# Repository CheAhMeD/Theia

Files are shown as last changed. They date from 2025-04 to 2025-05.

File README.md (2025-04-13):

# Theia Thermal Imaging Camera

<br>


Theia is an open source thermal camera designed around the ESP32-S3 and Lepton 3.5. <br>
It is started as a way to explore the Lepton 3.5 sensor and its abilities and turned to be a full (yet simple) thermal camera.

## Theia Camera
Theia is a well featured, open source camera with a local touchscreen display, local storage and a USB interface. <br>
It is composed of a custom PCB and a custom 3D enclosure (with optional stand).

<br>
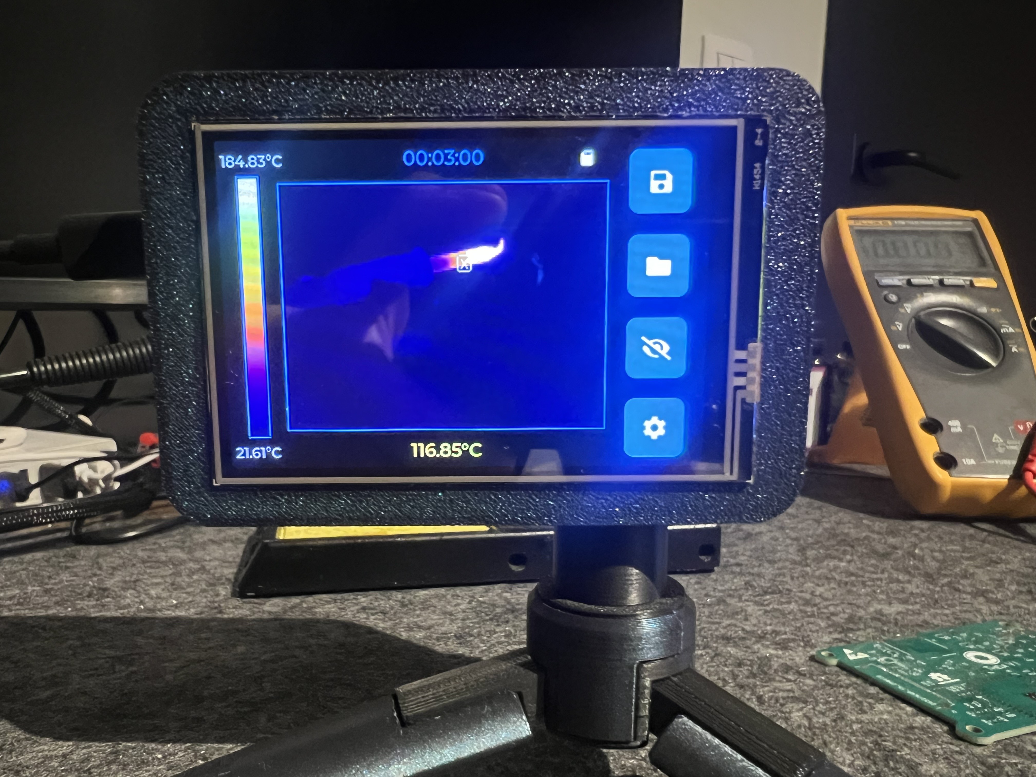
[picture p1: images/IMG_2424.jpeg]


## PCB
The PCB has been created with KiCAD software. <br>
Theia V1 Schematics are available in PCB Folder.<br>
The project is open source (If you need the KiCad project files drop a message). <br>
Please use the gerber files provided [here](/PCB/production.zip) if you want to order a PCB (The impedance control is important for the USB part to work). 

<br>
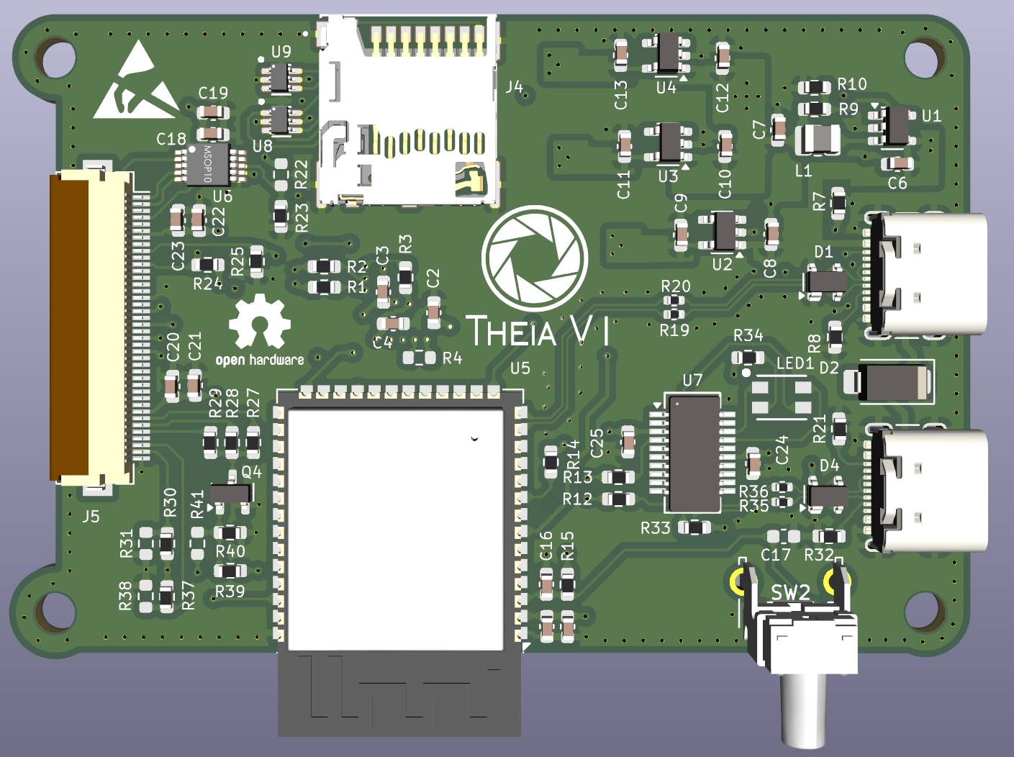
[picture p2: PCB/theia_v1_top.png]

<br>
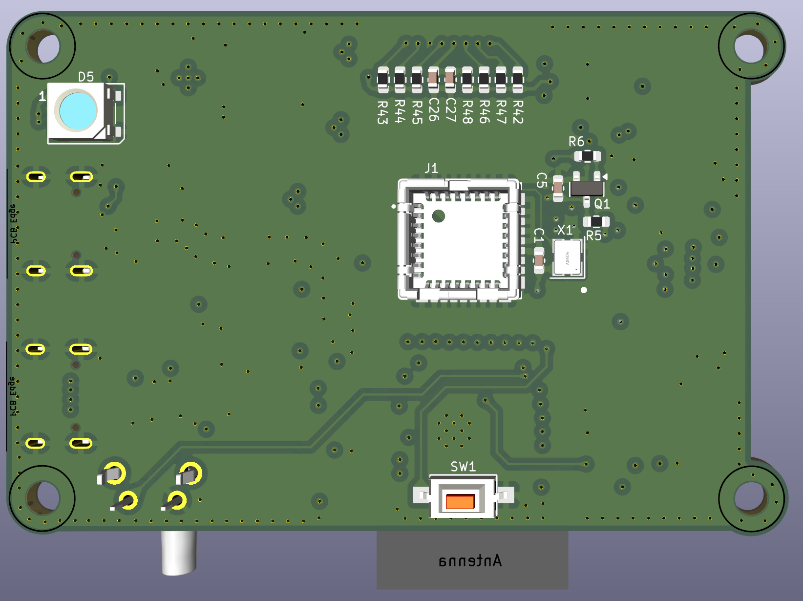
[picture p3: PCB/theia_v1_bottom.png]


## Firmware
The "Firmware" directory contains an Arduino IDE project for Theia (version 1). You should be able to build and load it into a camera using the normal process.

### Note:
Due to the custom pcb (no board package provided), to be able to upload the compiled firmware you need to set the Arduino Environment as follow:
<br>
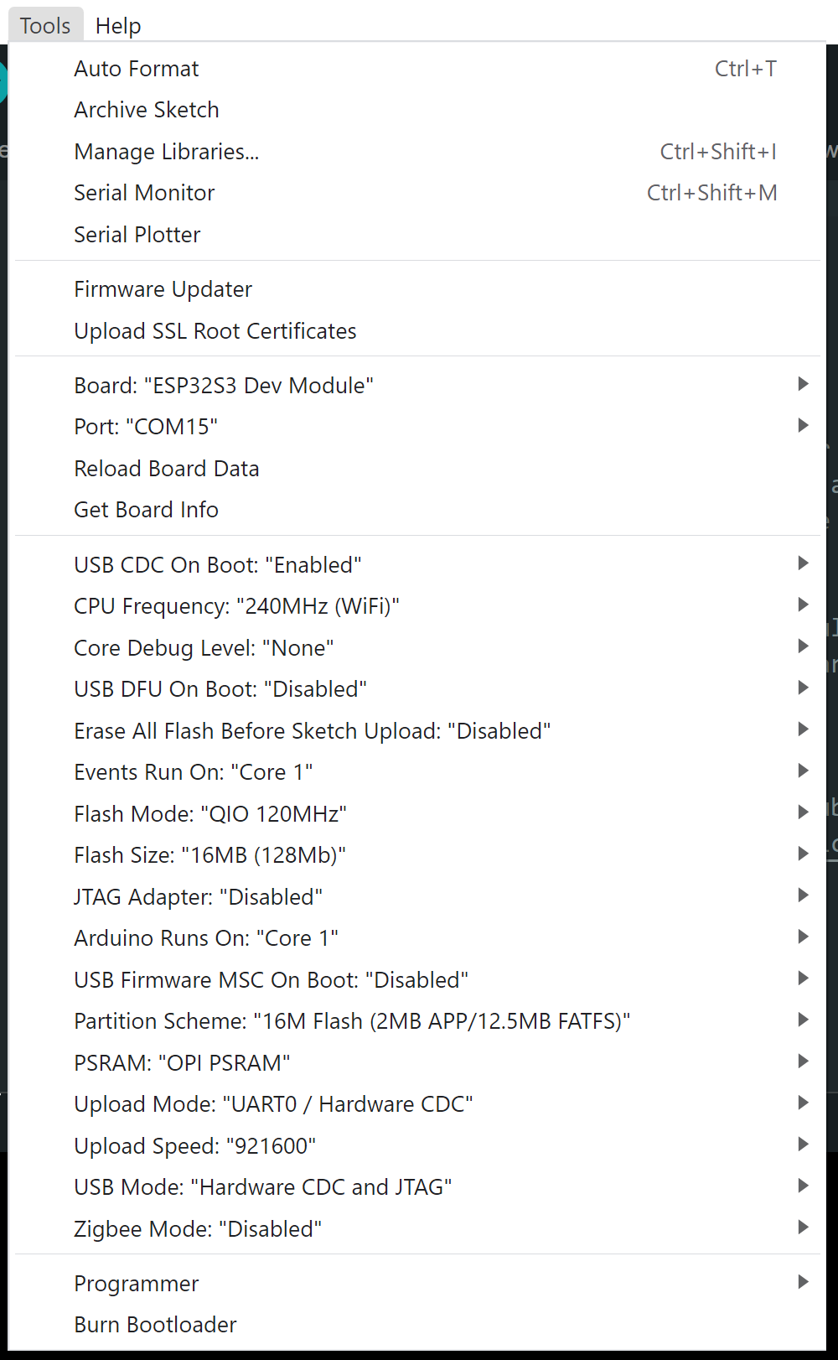
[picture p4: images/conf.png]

<br>
<br>
More details on the Firmware are available in /Firmware/README.md

## Enclosure
A simple 2 piece enclosure designed to be 3D printed. Design was done with the online editor "onshape". <br>
The OnShape project folder can be accessed [here](https://cad.onshape.com/documents/da13b0f788f852a632ae2d5d/w/38727c48ed0b2ebb656da7c0/e/01333a5db09d1259df274e6b) and the generated STL files are included in the Enclosure directory.

<br>
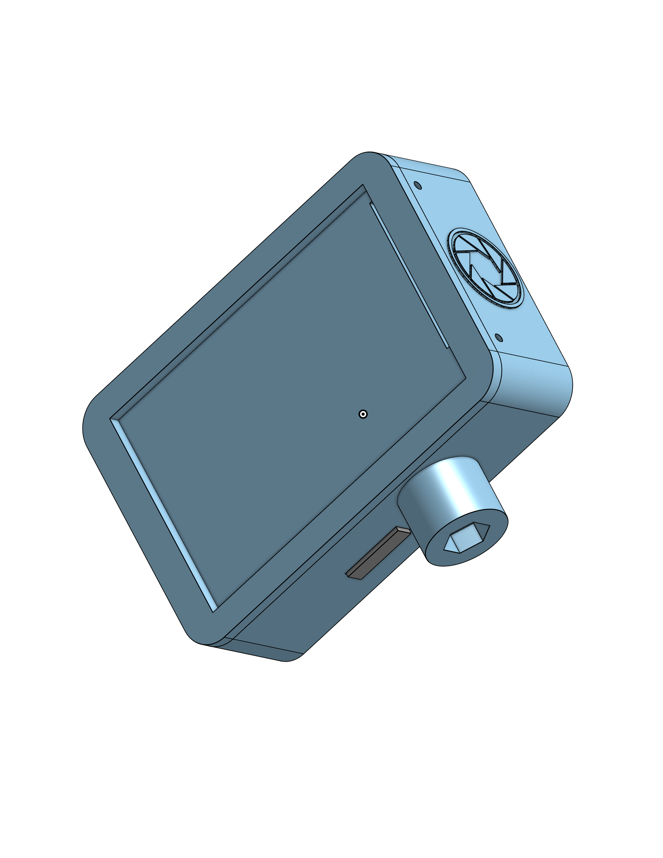
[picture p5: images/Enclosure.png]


## Desktop App
This DesktopApp folder contains the companion desktop application for Theia. It communicates with the cameras via a USB (Serial) connection using a predefined set of commands. 
It provides very basic functionalities to control the cameras, download and display images from them and analyze the radiometric data.

More details on the DesktopApp are available in /DesktopApp/README.md

## Python Examples
Simple Examples using a python script to perform basic operations on the camera.

## Acknowledgements
A lot of useful information were collected thanks to the brilliant work done in tCam (By [Dan Julio](https://github.com/danjulio)) and diy-thermocam (By [Max Ritter](https://github.com/maxritter))

 - [tCam](https://github.com/danjulio/tCam)
 - [DIY-Thermocam](https://github.com/maxritter/diy-thermocam)

## Authors

- [Che Ahmed](https://github.com/CheAhMeD)

## Badges



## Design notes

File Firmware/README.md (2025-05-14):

# Theia Thermal Camera - Firmware

Theia firmware V1 is an Arduino IDE project. You need to have the Arduino core for the ESP32 installed to build the firmware. <br>

## Dependencies 

[Display Driver] LovyanGFX 1.2.0 (a small modification needed for IPS Displays) <br>
[GUI] LVGL 8.3.0 <br> 
[Timer] ESP32Time 2.0.6 <br>
[Status Led] FastLED 3.9.13 <br>
[CRC] CRC 1.0.3 (Rob Tillaart)

## Operating

Theia can be controlled locally using the graphics user interface (Theia GUI) or remotely using a command-based interface (Theia Serial) available via USB. Both interfaces are detailed below.

### Theia USB Connector 1
The first USB Connector is used mainly for debug purposes (baud 115200) but it can be used to provide power to the camera. (By default the debug interface is disabled).

### Theia USB Connector 2
The USB connector is used to provide power to the camera and as a programming/control interface for Theia. This port is used by Theia Tool v1.0.0b to access the camera.

### Theia SD Card
Image files (RAW or BMP) are stored in the attached SD card. If none is attached the firmware will detect the absence of the SD Card and the user won't be able to save any images nor browse the content of the card. <br> Files are saved under RAW or BMP format (.timg or .bmp) after being scaled to 320x240.

#### Note:
**The SD Card must be formatted in FAT32.**
**Theia Hardware doesn't provide a Card Detect signal, the firmware uses a dumb routines that checks if a certain file (.theia) exists on the SD Card to determine that the SD Card is attached. The file ".theia" is created at boot if it doesnt exist.**

## Theia GUI

<br>
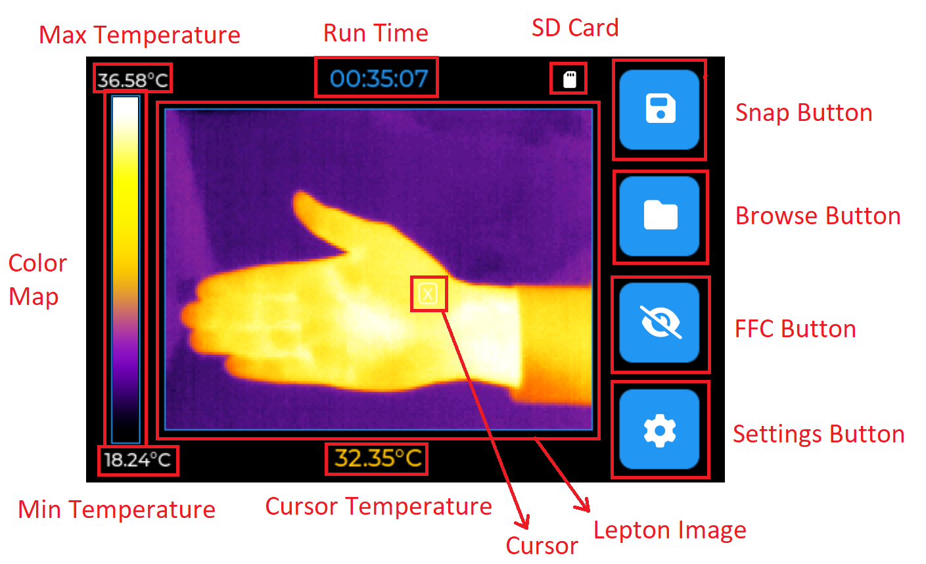
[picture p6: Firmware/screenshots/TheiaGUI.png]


### Boot Screen

A timed out screen that displays the logo and a boot log message.

<br>
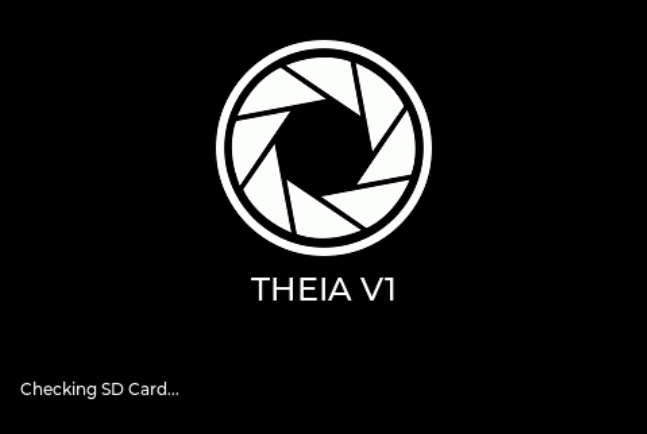
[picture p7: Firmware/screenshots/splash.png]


### Main Screen 

Camera main screen that contain the lepton stream and some controls.

<br>
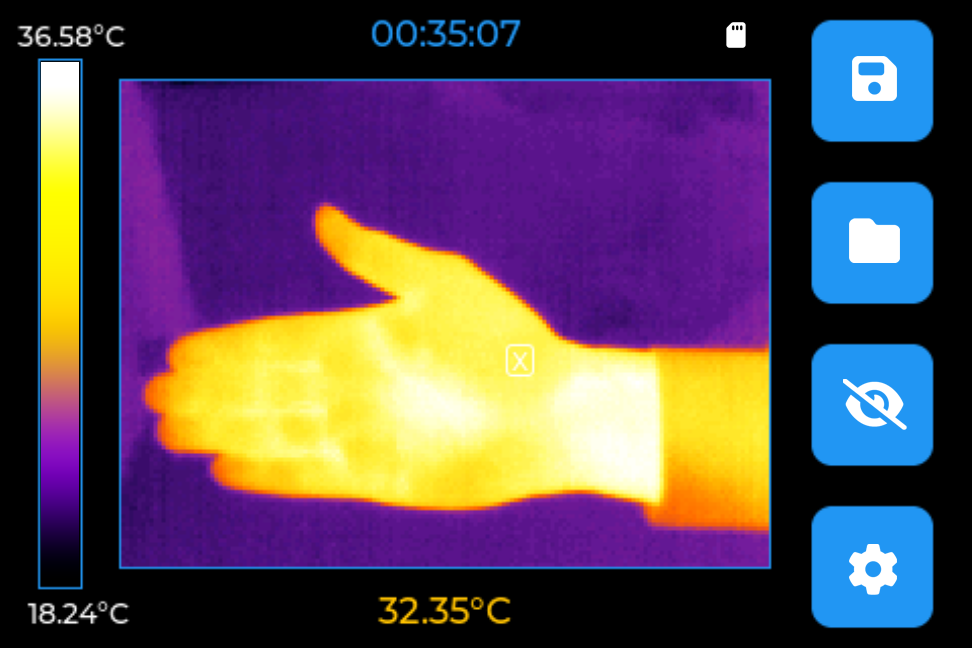
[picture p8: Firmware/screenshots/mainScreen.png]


#### Controls

| **Control** | **Function** |
|---|---|
| Snap Button  | Takes a snap and saves a BMP/TIMG image in the SD card under "Lepton" directory (a status message box will appear once pressed). |
| Browse Button  | Opens the browse screen. |
| FFC Button | Performs a manual FFC. |
| Settings Button | Opens the settings screen.  |
|  Cursor | Pressing on the lepton image updates the cursor position and the cursor temperature. |

### Browse Screen

SD card browse screen. A very simple gui to browse and display the content of "Lepton" directory. <br>
It shows the file name, file number and total files in the directory.

<br>
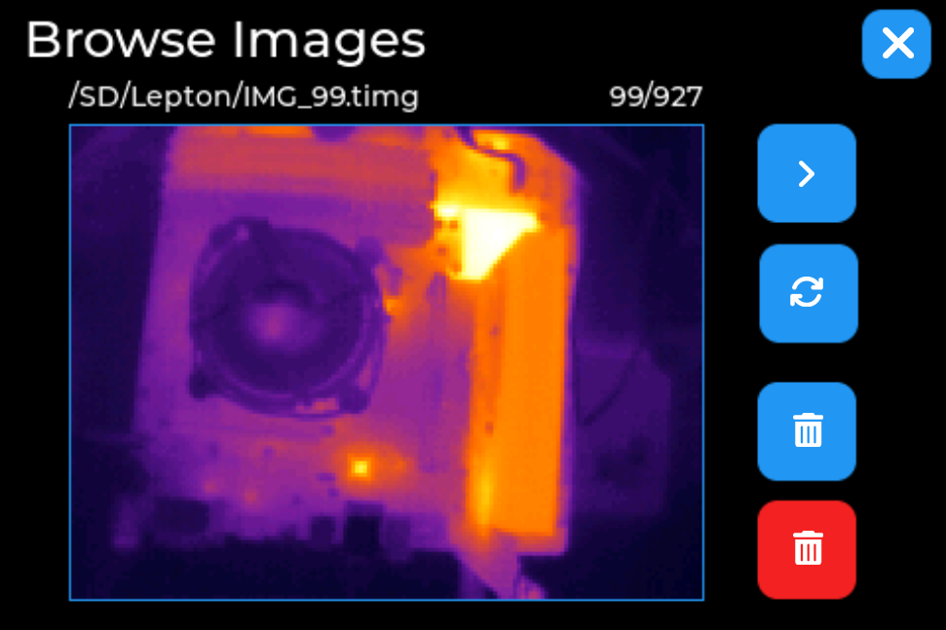
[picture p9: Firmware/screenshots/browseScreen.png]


#### Controls

| **Button** | **Function** |
|---|---|
| Close Button  | Returns to the main screen. |
| Next Button  | Displays the next image file. |
| Rewind Button | Goes back to the first file in the directory. |
| Detete Button | (In blue) Deletes the current displayed image (a confirmation message box will appear once pressed).  |
|  Delete All Button | (In red) Deletes all the files in Lepton Directory (a confirmation message box will appear once pressed).  |

### Settings Screen

Camera settings screen. It offers some controls over the behaviour of the camera as well as some controls over the lepton sensor.

<br>
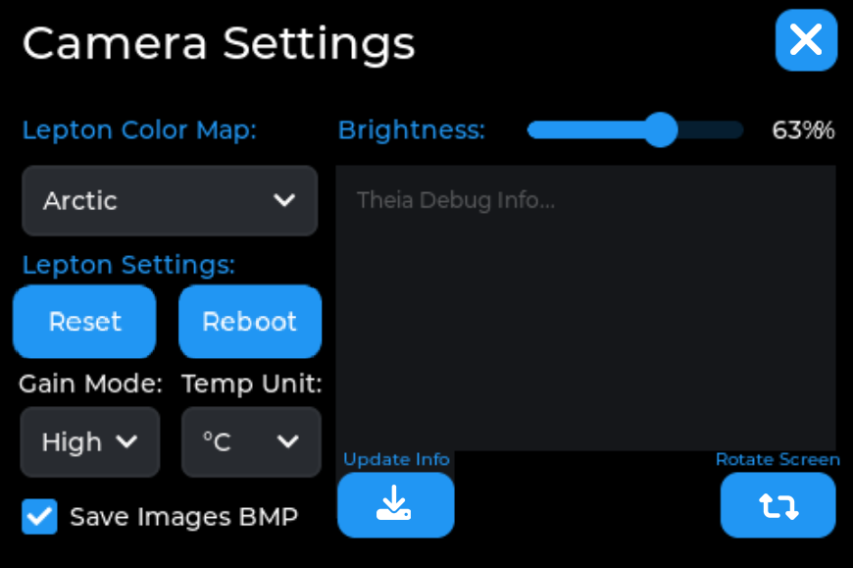
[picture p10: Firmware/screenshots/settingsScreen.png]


#### Controls

| **Control** | **Function** |
|---|---|
| Close Button  | Returns to the main screen. |
| Lepton Color Map | Updates the color map of the lepton image from the available 12 palettes. |
| Reset Button | Resets the lepton sensor (a status message box will appear once pressed).  |
| Reboot Button | Reboots the lepton sensor (a status message box will appear once pressed). |
| Gain Mode | Updates the lepton gain mode (High / Low / Auto). |
| Temp Unit | Updates the temperature unit (°C / °F / K). |
| Save Image BMP | Switches between .bmp / .timg formats for the saved image (using snap button). |
| Brightness | Updates the brightness of the display. |
| Update Info | Displays some diagnostics info in Theia Debug Info Box. |
| Rotate Screen | Rotates the screen 180°. |

## Theia Serial

Theia Serial inteface is meant for basic controls over the camera using the native USB (In CDC mode) on the ESP32-S3. <br>
The communication is simplistic and based on frames. Meaning the host (Desktop App | Python Script ...) sends a 1-byte command (Set | Get) to the camera and the camera responds with the adequate frame if the sent command corresponds to one of the commands else it responds with a NAK byte. <br>

### Data Frame

#### Host (Command):

Get Commnad:
| **CMD ID** |
|------------|
|   1 Byte   |

Set Command:
| **CMD ID** |  **DATA**  |
|---|---|
| 1 Byte | n Bytes  |

#### Device (Response):

Unvalid Command Response:
| **NAK** |
|---------|
|  0x05   |

Get Response:
| **ACK** | **CMD ID** | **DATA** | **CRC8** | 
|---|---|---|---|
|  0x10 | 1 Byte | n Bytes  | 1 Byte | 

Set Response (Success/Failure Frame):
| **ACK** | **CMD ID** | **STATE** |
|---|---|---|
|  0x10 | 1 Byte |  1 Byte |

**STATE** is either success (0x01) or failure (0x00).

### Command list

| **Command** | **Value** | **Description** |
|---|---|---|
| Get Lepton Status  | 0x73  | Returns a frame containing the Lepton Camera status.  |
| Get Lepton Diagnostics |  0x64  | Returns a frame containing diagnostics data on the lepton. |
| Get Image |  0x44 | Returns a frame containing the raw data captured from the camera. |
|  Get Spot Temp  | 0x74 | Returns a frame containing a string of current spotmeter temperature.  |
|  Get Run Time | 0x52 | Returns a frame containing a string of current camera runtime. |
|  Get Storage Info | 0x69 |  Returns a frame containing SD Card info. |
| | | |
|  Lepton Reboot | 0x42 | Reboots the lepton and returns a success/failure frame.  |
|  Lepton Reset | 0x72 | Resets the lepton and returns a success/failure frame.  |
|  Run FFC | 0x46 | Runs an FFC and returns a success/failure frame.  |
| | | |
| Set ColorMap  |  0x43 |  Updates the colormap on the camera. Requires 1 byte of data (colormap id). |
| Set Lepton Gain |  0x47 |  Updates the lepton gain. Requires 1 byte of data (gain type). |
| Set Spotmeter Position |  0x70 |  Updates the position of the spotmeter on the camera. Requires 2 bytes of data (x and y). |

#### NOTE:
**For more details about the communication framing refer to Connection.h and Connection.cpp in firmware folder.**

## Authors

- [Che Ahmed](https://github.com/CheAhMeD)

## Badges



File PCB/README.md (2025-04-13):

## Used Hardware
### Required
- Theia PCB ([Schematics](theia_v1_schematics.pdf))
- Lepton Flir 3.5 ([mouser](https://mou.sr/42w5bx5))
- LCD IPS 3.5 Touch 9488 ([AliExpress](https://www.aliexpress.com/item/1005007513268466.html))
- Custom 3D Case ([STL Files](../Enclosure))
### Optional
- Tripod ([3D Model](https://makerworld.com/en/models/671280-folding-tripod-two-sizes))
- Stylus ([3D Model](https://www.printables.com/model/117004-stylus-pen-for-resitive-touch-screens))

## Authors

- [@CheAhmed](https://github.com/CheAhMeD)

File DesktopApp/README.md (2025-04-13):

# Theia Desktop Application

This repository contains the companion desktop application for the Theia cameras. It communicates with the cameras via a Serial connection using a one-byte command set. It provides functionality to control the cameras, download and display data from them and analyze the radiometric data. <br>

The application is developed using python (PySide6). A Windows image is provided in a zip file. The application can be run directly from the unzipped directory by double clicking the application executable.

## Overview

The different controls are listed below.

<br>
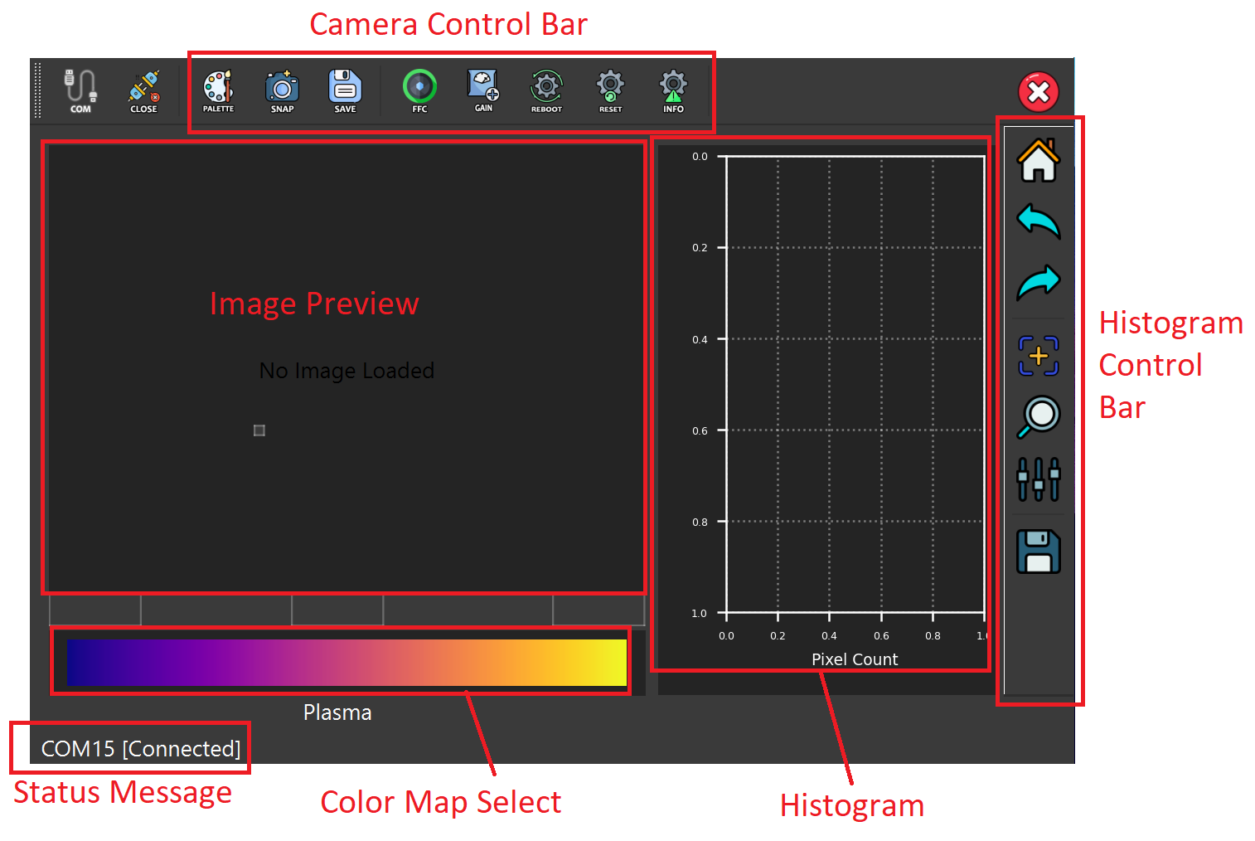
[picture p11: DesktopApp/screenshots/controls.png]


## Usage

### Startup

Double clicking the application executable will start the app.

<br>
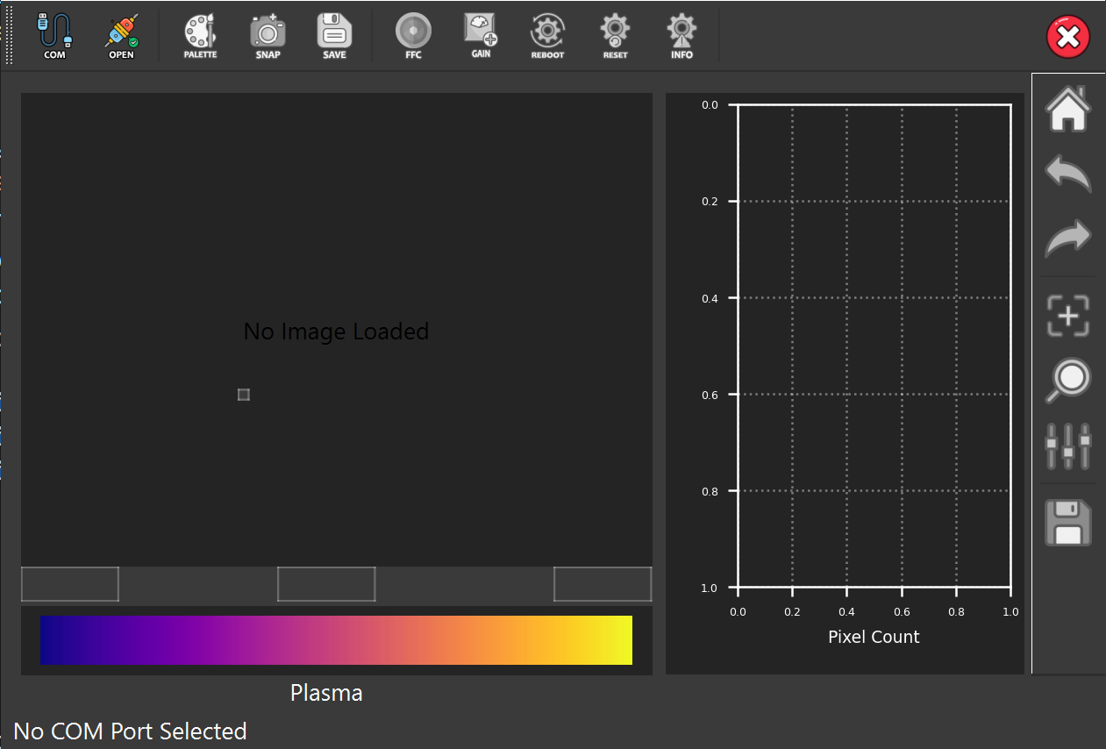
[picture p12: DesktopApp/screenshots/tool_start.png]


Note that most controls are disabled for now. They will be enabled once a successful connection to a camera is established.

### Connect a camera

Conncting a camera is a straight foward procedures; you need to first select a port com using the select com button (make sure it's the right one).

<br>
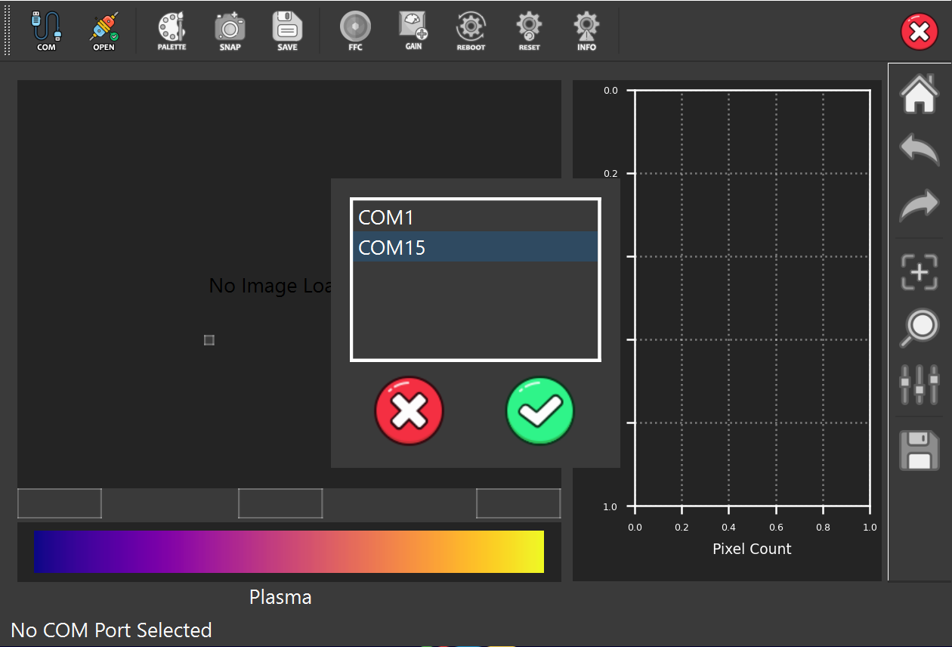
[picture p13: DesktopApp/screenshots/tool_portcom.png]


Then click on the connect button.

<br>
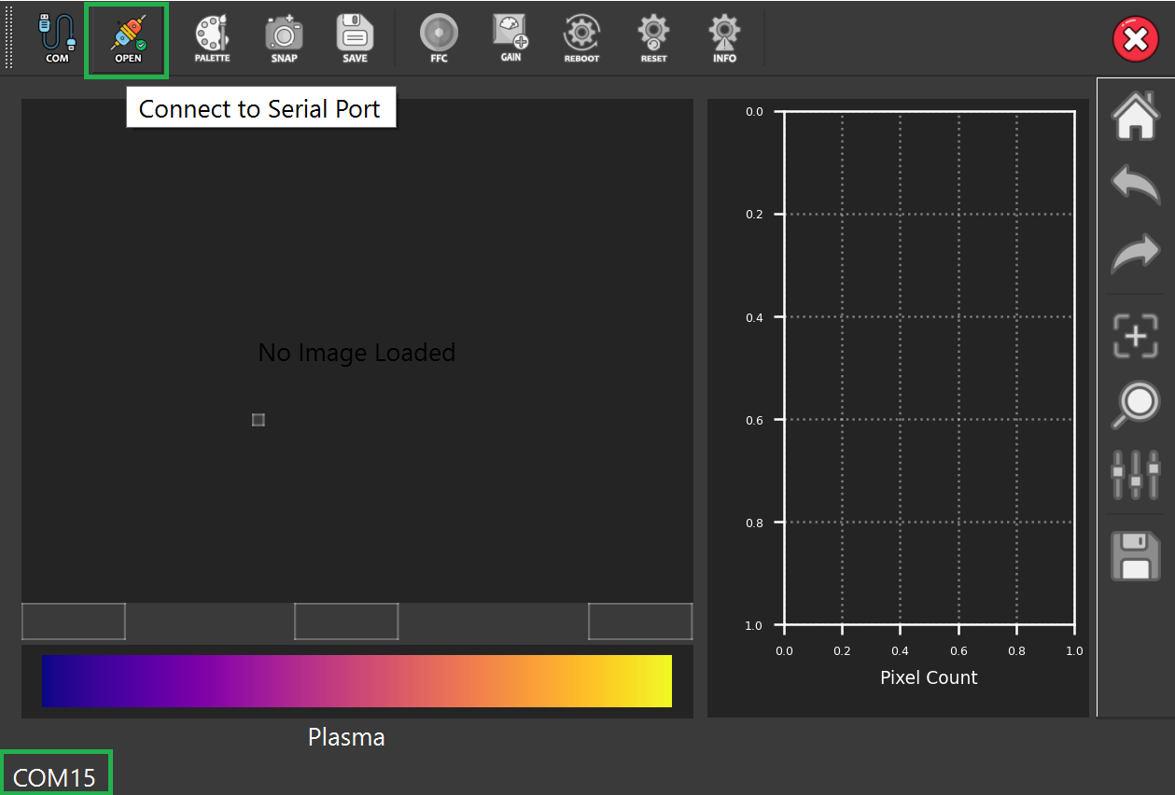
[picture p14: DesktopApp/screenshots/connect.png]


After a successful connection the remaining controls will be enabled.

<br>
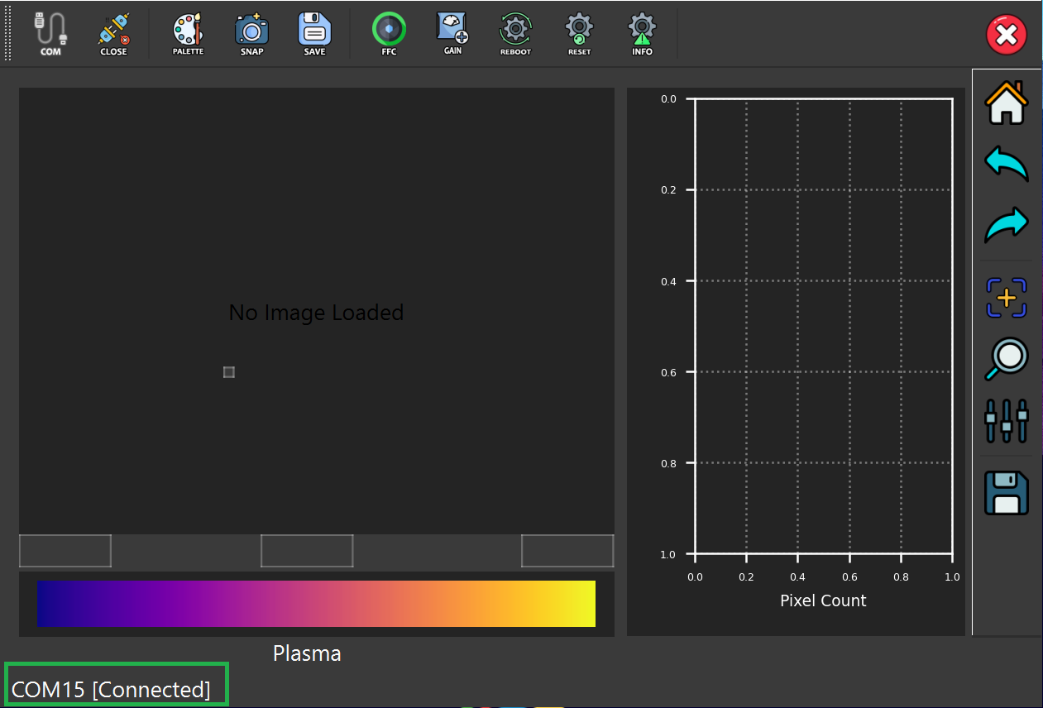
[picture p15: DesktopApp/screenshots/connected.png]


### Camera Controls

The app tool bar, beside establishing a connection, it provides some basic controls. These buttons provide a way to send commands to the camera over the serial interface.

<br>


| **Control** | **Function** |
|---|---|
| Palette Button  | Opens a Colormap Select Dialog where the user can select one of the predefined colormaps and click on confirm to send "set colormap" command to the camera (The camera should change the colormap immediately)|
| Snap Button  | Sends "get raw data" command to the camera. Upon receiving the full image it will be displayed in Image Preview. |
| Save Button | Opens a dialog to save the currently displayed image (as png). |
| FFC Button | Sends "run ffc" command to the camera. |
| Gain Button | Open a dialog to select a gain (High/Low/Auto) and sends "set gain" command to the camera upon confirming.  |
| Reboot Button | Sends "reboot" command to the camera.  |
| Reset Button | Sends "reset" command to the camera. |
| Info Button | Sends "get info" command to the camera and opens a dialog to display the received info. |

### Image Controls

The image preview section provides some info on the maximum & minimum temperatures (in °C) over the received image. You can also click anywhere on the image to select a spot and get the temperature. A cursor is dynamically drawn over the selected spot.

<br>
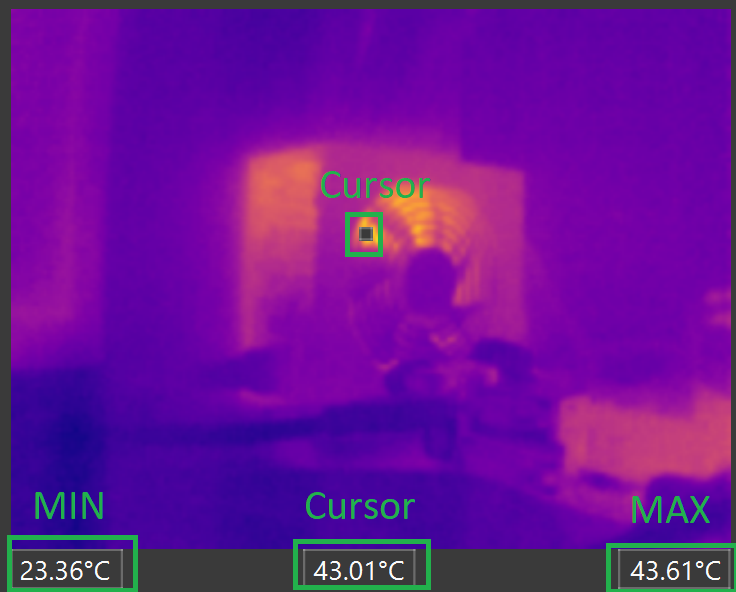
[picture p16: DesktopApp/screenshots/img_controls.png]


### Colormap Controls

Clicking on either the left or the right side of the colormap would load another one of the predefined colormpas. Right for next and Left for previous. The name of the selected colormap is displayed and the and the color theme is reapplied on the dislayed image and histogram.

<br>
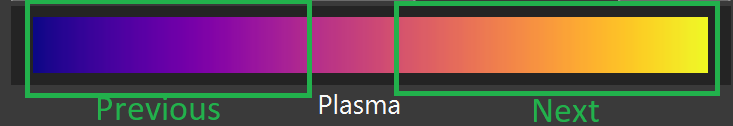
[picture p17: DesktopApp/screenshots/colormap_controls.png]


### Histogram Controls

The histogram tool bar offers some basic control over the displayed figure.

<br>


more details about the controls can be found [here](https://matplotlib.org/3.2.2/users/navigation_toolbar.html).

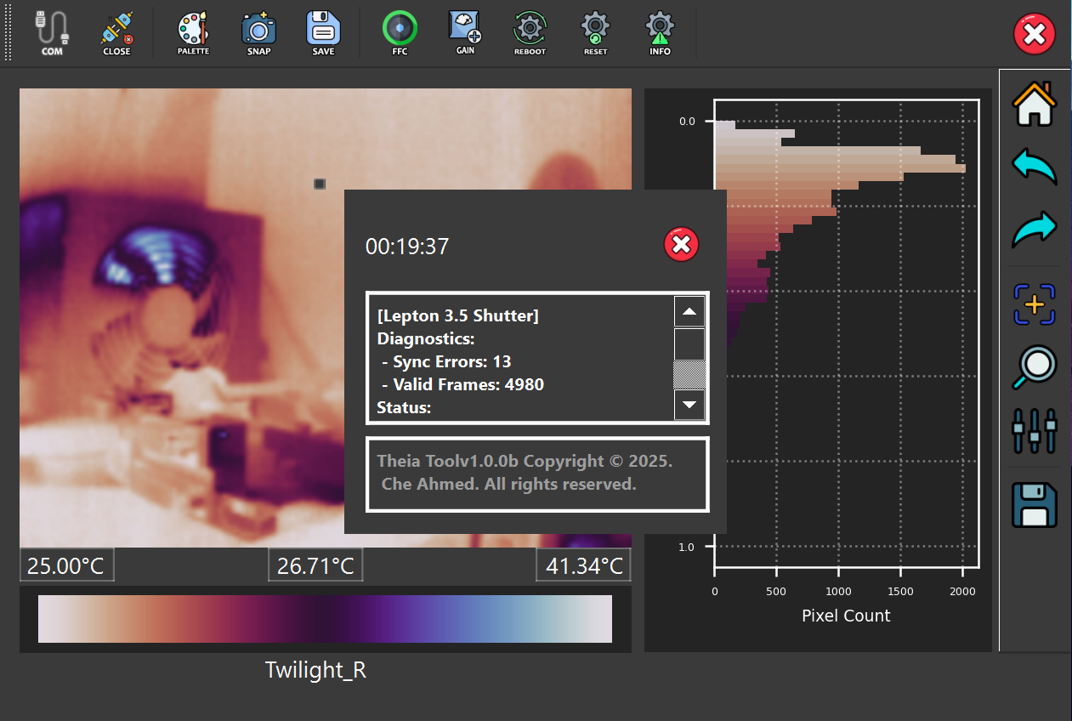
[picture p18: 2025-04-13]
DesktopApp/screenshots/info.png

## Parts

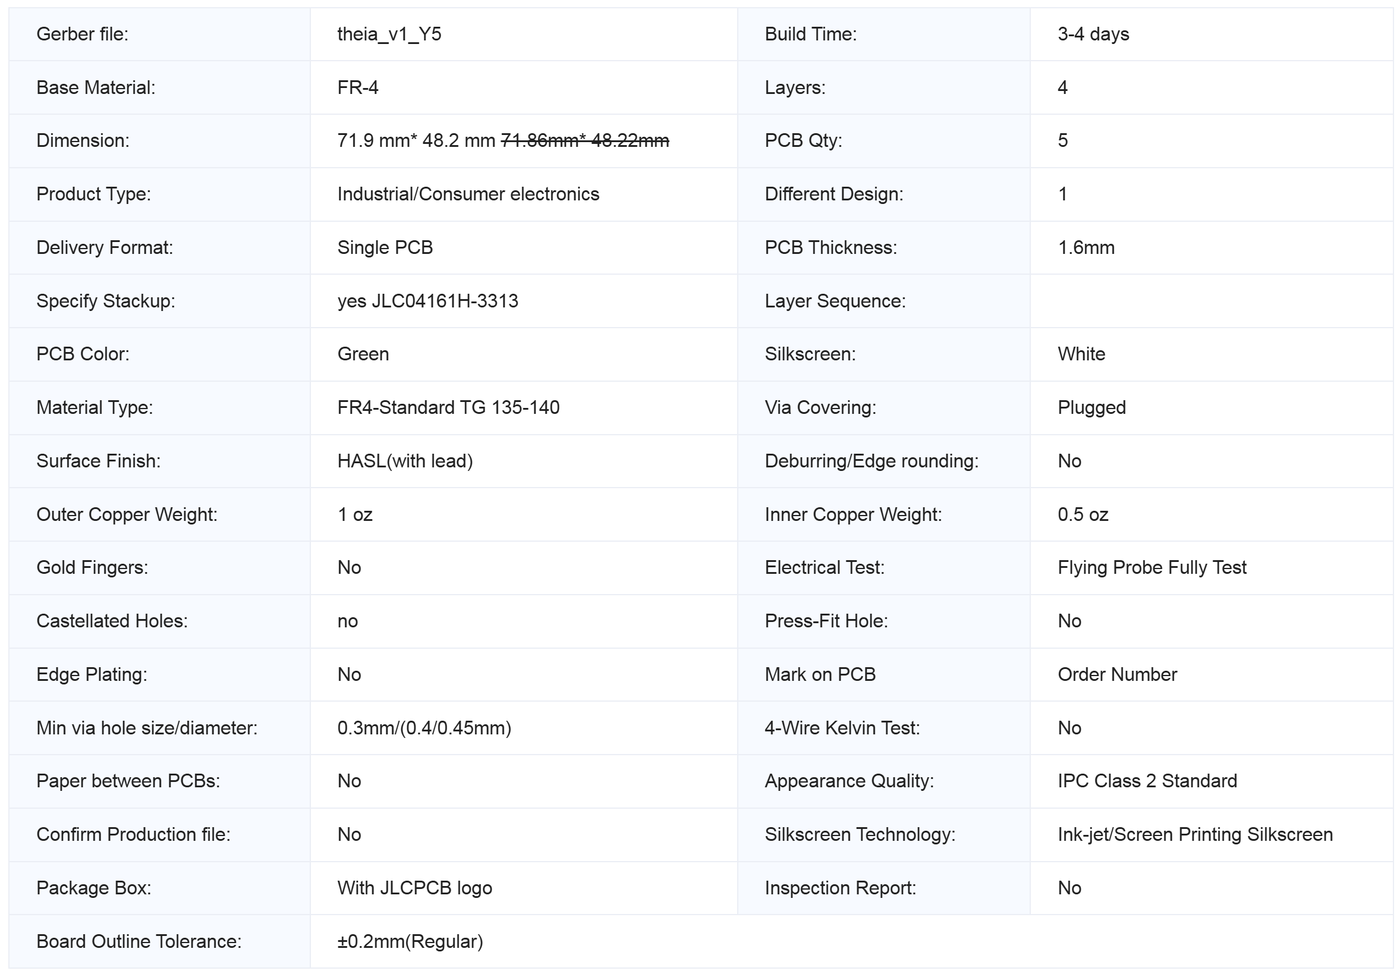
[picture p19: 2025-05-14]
PCB/jlcpcb_order.png

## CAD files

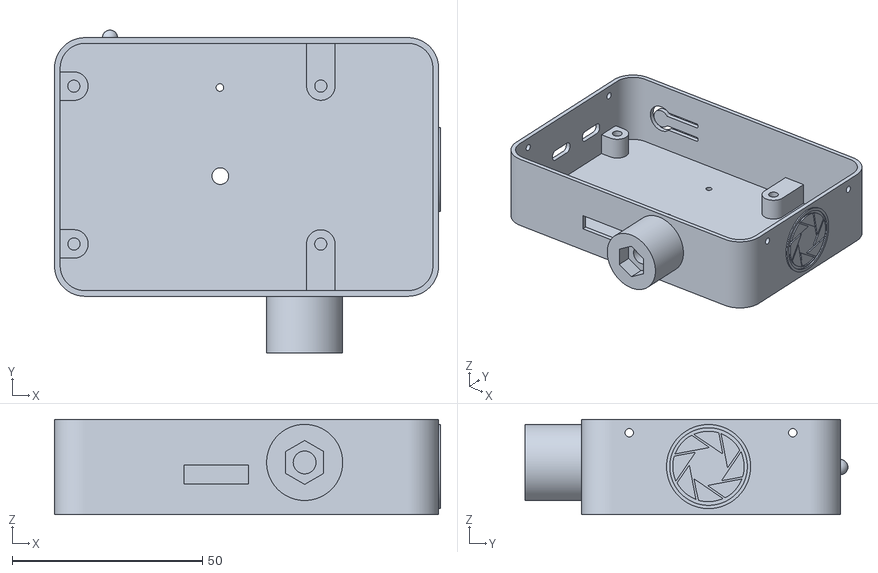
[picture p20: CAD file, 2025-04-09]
Enclosure/case_bottom.stl
101.5 x 84.9 x 25.0

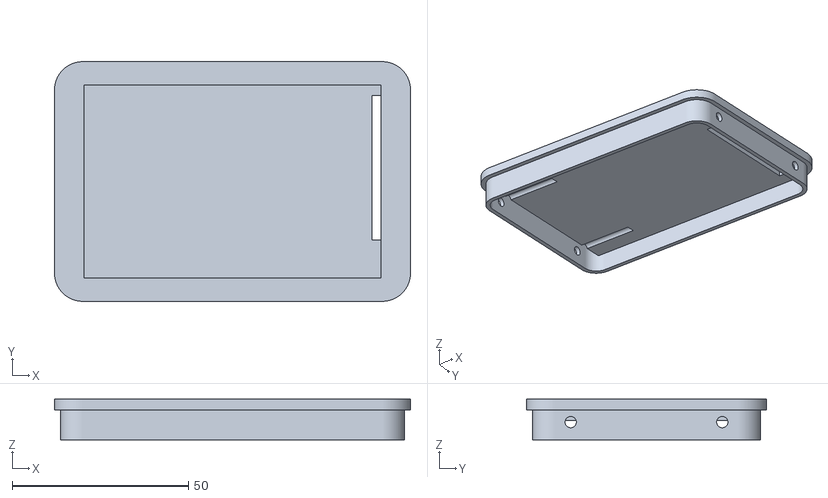
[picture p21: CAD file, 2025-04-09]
Enclosure/case_lid.stl
101.0 x 68.0 x 11.5

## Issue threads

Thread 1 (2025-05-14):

Ordering Information / Further Info

Graffics, 2025-05-14:
Hi @CheAhMeD

Found this design quite novel via your reddit post.
I'm looking to build a Theia V1 and just needed to grab some further info from you if possible.
I've sectioned out the few queries below - appreciate your time in advance

**ESP32-S3-WROOM-1**
What variant of ESP32-S3 is needed?

From the flashing config it's clear you used a 16MB flash variant with some form of PSRAM
I've tried compiling the firmware to work out the size needed without much success (detailed later on)
What size flash is needed? And what size of PSRAM?

--

**Assembly Work**

From the reddit comments, it's clear you assembled this on your own rather than ordering for assembly
How did you go about assembling it? Via a hotplate? or hand soldered? Some of both?
If via a hotplate, I'm assuming you would have ordered a stencil via JLC when you ordered the PCB?

--

**PCB Ordering**

It's noted in the readme to use the gerber zip for impedance control.
Is anything required to be set under 'layer sequence' or 'stackup' regarding the impedance?
Surface Finish: Leadfree HASL or ENIG?

If possible, could you confirm if there's any required specifications that aren't the default on the JLCPCB ordering page?
I've attached an ordering page screenshot if needed below:

<details>
<summary> Expand for image: </summary>

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

</details>
--

**Firmware Compilation: Missing Library?**

From attempting to compile the firmware in the Arduino IDE (version 2.3.6) ran into an issue missing a dependency for the CRC Libraries - which isn't listed in the dependencies section of the FW readme.
I installed the latest 1.0.3 version of 'CRC' by Rob Tillaart - is this the correct library and version?

--

**Firmware Compilation: LVGL Config?**

After resolving the CRC Library I'm still unable to compile the firmware.

If compiling after installing LVGL and dependencies, LVGL complains about missing a config file.

<details open>
<summary> Error Log: </summary>

```
In file included from c:/Users/User/Documents/Arduino/libraries/lvgl/src/misc/lv_log.h:16,
                 from c:/Users/User/Documents/Arduino/libraries/lvgl/lvgl.h:25,
                 from C:\Users\User\Documents\Arduino\libraries\lvgl\src/lvgl.h:17,
                 from C:\Users\User\Downloads\Theia-V1\Theia-main\Firmware\theia_v1\theia_v1.ino:1:
c:/Users/User/Documents/Arduino/libraries/lvgl/src/lv_conf_internal.h:41:18: fatal error: ../../lv_conf.h: No such file or directory
   41 |         #include "../../lv_conf.h"                /*Else assume lv_conf.h is next to the lvgl folder*/
      |                  ^~~~~~~~~~~~~~~~~
compilation terminated.
exit status 1

Compilation error: exit status 1
```
</details>

I manually copied the provided template file as it instructs. This allows it to continue further (however still not fully). I'm not sure if the config needs to be customized?

The errors after copying the template config seem to be some issues with LVGL declarations surrounding the fonts and panel type.
Is a custom lv_conf file required? If so, are you able to include it in this repository?
Are additional fonts required that I may not have installed?

Error log below:

<details>
<summary> Error Log: </summary>

```
In file included from c:/Users/User/Documents/Arduino/libraries/lvgl/src/misc/lv_log.h:16,
                 from c:/Users/User/Documents/Arduino/libraries/lvgl/lvgl.h:25,
                 from C:\Users\User\Documents\Arduino\libraries\lvgl\src/lvgl.h:17,
                 from C:\Users\User\Downloads\Theia-V1\Theia-main\Firmware\theia_v1\screens.h:4,
                 from C:\Users\User\Downloads\Theia-V1\Theia-main\Firmware\theia_v1\screens.c:3:
c:/Users/User/Documents/Arduino/libraries/lvgl/src/lv_conf_internal.h:46:17: note: '#pragma message: Possible failure to include lv_conf.h, please read the comment in this file if you get errors'
   46 |         #pragma message("Possible failure to include lv_conf.h, please read the comment in this file if you get errors")
      |                 ^~~~~~~
C:\Users\User\Downloads\Theia-V1\Theia-main\Firmware\theia_v1\screens.c: In function 'create_screen_main_screen':
C:\Users\User\Downloads\Theia-V1\Theia-main\Firmware\theia_v1\screens.c:98:40: error: 'lv_font_montserrat_18' undeclared (first use in this function); did you mean 'lv_font_montserrat_14'?
   98 |       lv_obj_set_style_text_font(obj, &lv_font_montserrat_18, LV_PART_MAIN | LV_STATE_DEFAULT);
      |                                        ^~~~~~~~~~~~~~~~~~~~~
      |                                        lv_font_montserrat_14
C:\Users\User\Downloads\Theia-V1\Theia-main\Firmware\theia_v1\screens.c:98:40: note: each undeclared identifier is reported only once for each function it appears in
C:\Users\User\Downloads\Theia-V1\Theia-main\Firmware\theia_v1\screens.c:128:44: error: 'lv_font_montserrat_24' undeclared (first use in this function); did you mean 'lv_font_montserrat_14'?
  128 |           lv_obj_set_style_text_font(obj, &lv_font_montserrat_24, LV_PART_MAIN | LV_STATE_DEFAULT);
      |                                            ^~~~~~~~~~~~~~~~~~~~~
      |                                            lv_font_montserrat_14
C:\Users\User\Downloads\Theia-V1\Theia-main\Firmware\theia_v1\screens.c:252:40: error: 'lv_font_montserrat_12' undeclared (first use in this function); did you mean 'lv_font_montserrat_14'?
  252 |       lv_obj_set_style_text_font(obj, &lv_font_montserrat_12, LV_PART_MAIN | LV_STATE_DEFAULT);
      |                                        ^~~~~~~~~~~~~~~~~~~~~
      |                                        lv_font_montserrat_14
C:\Users\User\Downloads\Theia-V1\Theia-main\Firmware\theia_v1\screens.c: In function 'create_screen_settings_screen':
C:\Users\User\Downloads\Theia-V1\Theia-main\Firmware\theia_v1\screens.c:355:44: error: 'lv_font_montserrat_24' undeclared (first use in this function); did you mean 'lv_font_montserrat_14'?
  355 |           lv_obj_set_style_text_font(obj, &lv_font_montserrat_24, LV_PART_MAIN | LV_STATE_DEFAULT);
      |                                            ^~~~~~~~~~~~~~~~~~~~~
      |                                            lv_font_montserrat_14
C:\Users\User\Downloads\Theia-V1\Theia-main\Firmware\theia_v1\screens.c:365:40: error: 'lv_font_montserrat_26' undeclared (first use in this function); did you mean 'lv_font_montserrat_14'?
  365 |       lv_obj_set_style_text_font(obj, &lv_font_montserrat_26, LV_PART_MAIN | LV_STATE_DEFAULT);
      |                                        ^~~~~~~~~~~~~~~~~~~~~
      |                                        lv_font_montserrat_14
C:\Users\User\Downloads\Theia-V1\Theia-main\Firmware\theia_v1\screens.c:431:40: error: 'lv_font_montserrat_12' undeclared (first use in this function); did you mean 'lv_font_montserrat_14'?
  431 |       lv_obj_set_style_text_font(obj, &lv_font_montserrat_12, LV_PART_MAIN | LV_STATE_DEFAULT);
      |                                        ^~~~~~~~~~~~~~~~~~~~~
      |                                        lv_font_montserrat_14
C:\Users\User\Downloads\Theia-V1\Theia-main\Firmware\theia_v1\screens.c:467:40: error: 'lv_font_montserrat_10' undeclared (first use in this function); did you mean 'lv_font_montserrat_14'?
  467 |       lv_obj_set_style_text_font(obj, &lv_font_montserrat_10, LV_PART_MAIN | LV_STATE_DEFAULT);
      |                                        ^~~~~~~~~~~~~~~~~~~~~
      |                                        lv_font_montserrat_14
C:\Users\User\Downloads\Theia-V1\Theia-main\Firmware\theia_v1\screens.c: In function 'create_screen_browse_screen':
C:\Users\User\Downloads\Theia-V1\Theia-main\Firmware\theia_v1\screens.c:681:44: error: 'lv_font_montserrat_24' undeclared (first use in this function); did you mean 'lv_font_montserrat_14'?
  681 |           lv_obj_set_style_text_font(obj, &lv_font_montserrat_24, LV_PART_MAIN | LV_STATE_DEFAULT);
      |                                            ^~~~~~~~~~~~~~~~~~~~~
      |                                            lv_font_montserrat_14
C:\Users\User\Downloads\Theia-V1\Theia-main\Firmware\theia_v1\screens.c:691:40: error: 'lv_font_montserrat_26' undeclared (first use in this function); did you mean 'lv_font_montserrat_14'?
  691 |       lv_obj_set_style_text_font(obj, &lv_font_montserrat_26, LV_PART_MAIN | LV_STATE_DEFAULT);
      |                                        ^~~~~~~~~~~~~~~~~~~~~
      |                                        lv_font_montserrat_14
C:\Users\User\Downloads\Theia-V1\Theia-main\Firmware\theia_v1\screens.c:798:40: error: 'lv_font_montserrat_18' undeclared (first use in this function); did you mean 'lv_font_montserrat_14'?
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
CheAhMeD, 2025-05-14:
Hello @Graffics,

Thanks for your interest in Theia V1. Here is the additional info you asked:

**What variant of ESP32-S3 is needed?**
I used _ESP32-S3-WROOM-1-n16r8_ from Aliexpress [(here)](https://www.aliexpress.com/item/1005006633393921.html)

**How did you go about assembling it?**
I hand soldered everything... Well I have a hot gun and a digital microscope which helped a lot.
I only used the hotgun for the bottom layer where the lepton3.5 socket and oscillator are placed. The rest I only used a soldering iron with a fine tip and the microscope.

**Is anything required to be set under 'layer sequence' or 'stackup' regarding the impedance?**
The stackup is already considered while generating the gerber files... You don't need to change anything
**Surface Finish: Leadfree HASL or ENIG?**
That depends on your taste (gold finish or grey finish)

**could you confirm if there's any required specifications that aren't the default on the JLCPCB ordering page?**
Here is my order details. You can cross check
<br>
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

**I installed the latest 1.0.3 version of 'CRC' by Rob Tillaart - is this the correct library and version?**
Yes that is the correct one (I updated the dependency list). <br>

**Firmware Compilation: LVGL Config?**
I added the config file lv_conf.h to the Firmware folder. <br>
Just replace the file you copied with the new file and you should be good to go. <br>

If you have further issues, please follow the instructions here to get it to work [LVGL Configuration](https://docs.lvgl.io/master/details/integration/adding-lvgl-to-your-project/configuration.html)

CheAhMeD, 2025-05-14:
Hello @Graffics,

Thanks for your interest in Theia V1. Here is the additional info you asked:

**What variant of ESP32-S3 is needed?**
I used _ESP32-S3-WROOM-1-n16r8_ from Aliexpress [(here)](https://www.aliexpress.com/item/1005006633393921.html)

**How did you go about assembling it?**
I hand soldered everything... Well I have a hot gun and a digital microscope which helped a lot.
I only used the hotgun for the bottom layer where the lepton3.5 socket and oscillator are placed. The rest I only used a soldering iron with a fine tip and the microscope.

**Is anything required to be set under 'layer sequence' or 'stackup' regarding the impedance?**
The stackup is already considered while generating the gerber files... You don't need to change anything
**Surface Finish: Leadfree HASL or ENIG?**
That depends on your taste (gold finish or grey finish)

**could you confirm if there's any required specifications that aren't the default on the JLCPCB ordering page?**
I uploaded my order details in the PCB folder. You can cross check

**I installed the latest 1.0.3 version of 'CRC' by Rob Tillaart - is this the correct library and version?**
Yes that is the correct one (I updated the dependency list). <br>

**Firmware Compilation: LVGL Config?**
I added the config file lv_conf.h to the Firmware folder. <br>
Just replace the file you copied with the new file and you should be good to go. <br>

If you have further issues, please follow the instructions here to get it to work [LVGL Configuration](https://docs.lvgl.io/master/details/integration/adding-lvgl-to-your-project/configuration.html)

Closed 2025-05-14.

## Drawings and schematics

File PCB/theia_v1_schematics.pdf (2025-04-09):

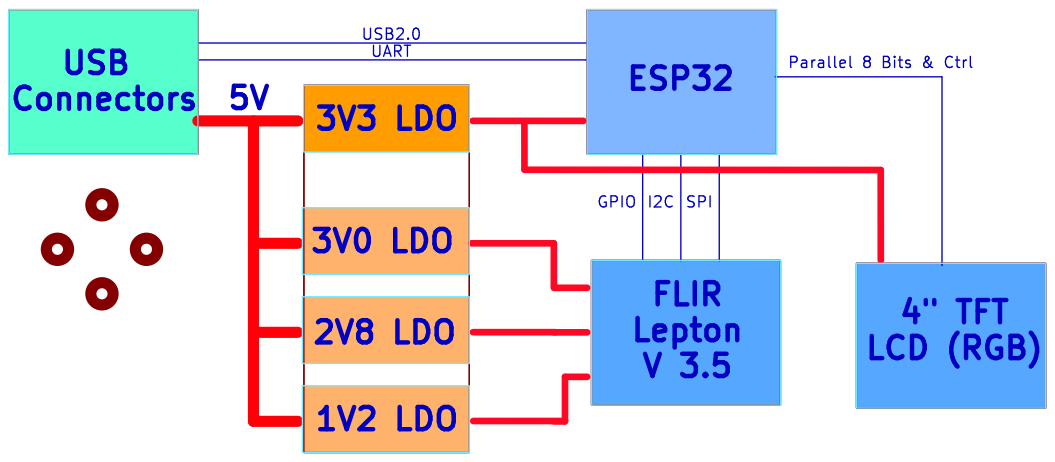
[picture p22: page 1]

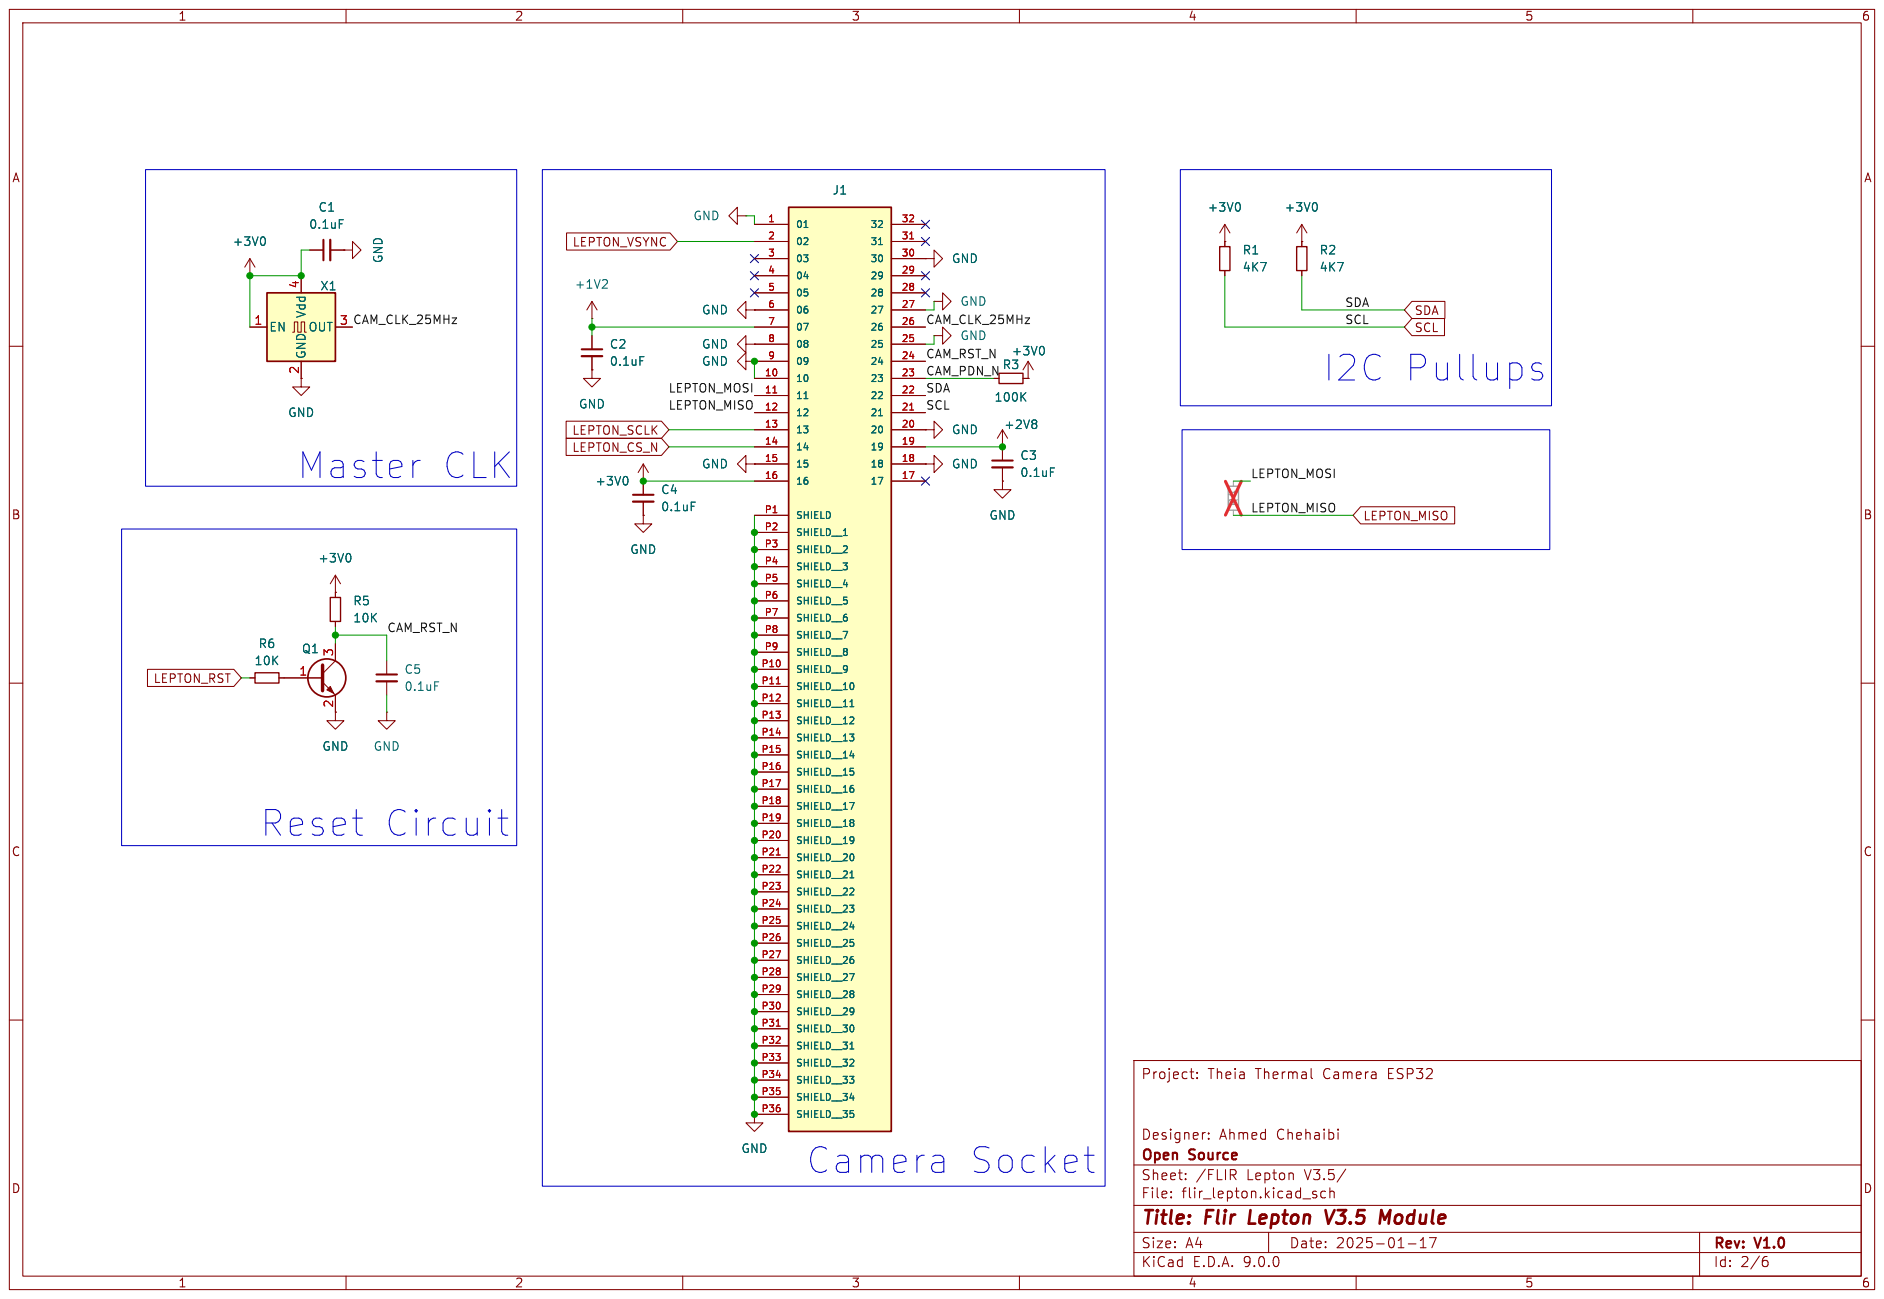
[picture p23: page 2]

Id: 2/6 Title: Flir Lepton V3.5 Module

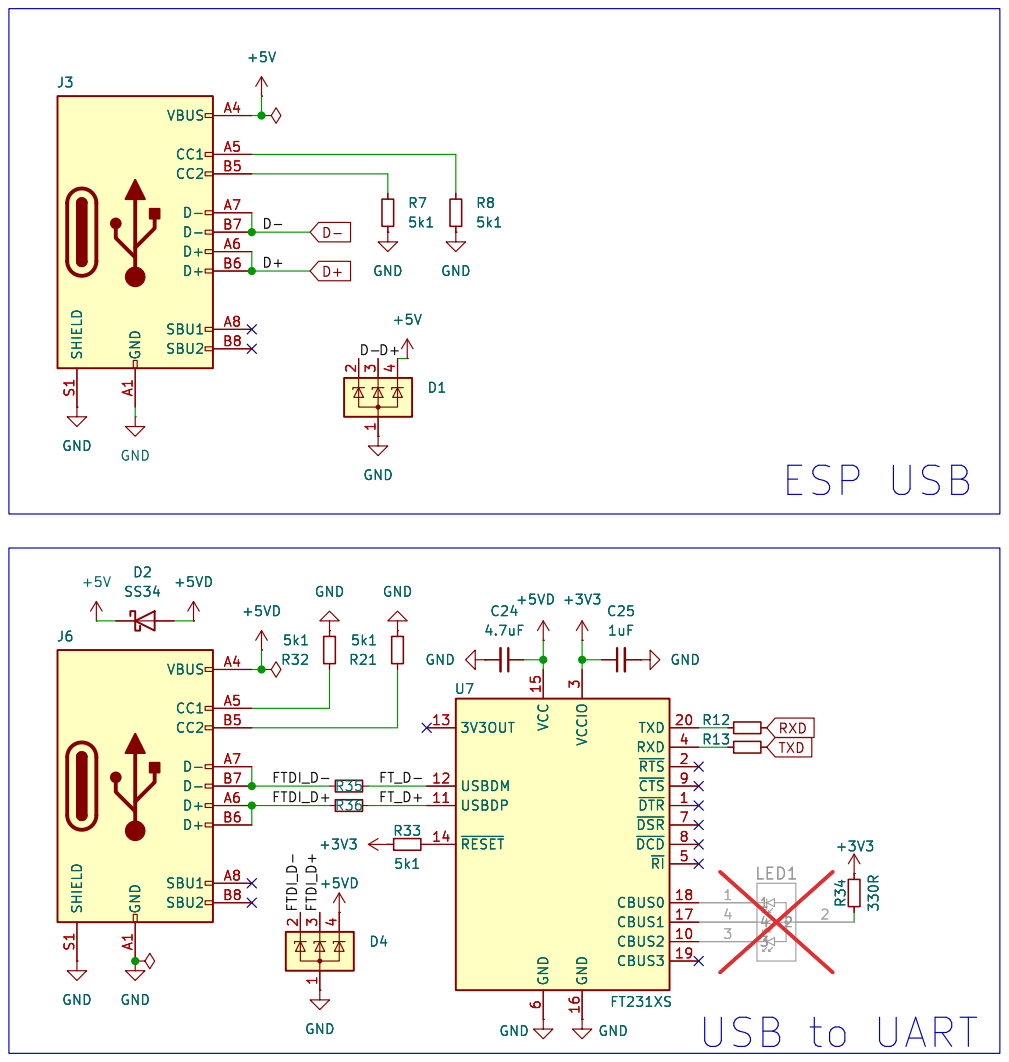
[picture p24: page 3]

Id: 3/6 Title: USB & UART

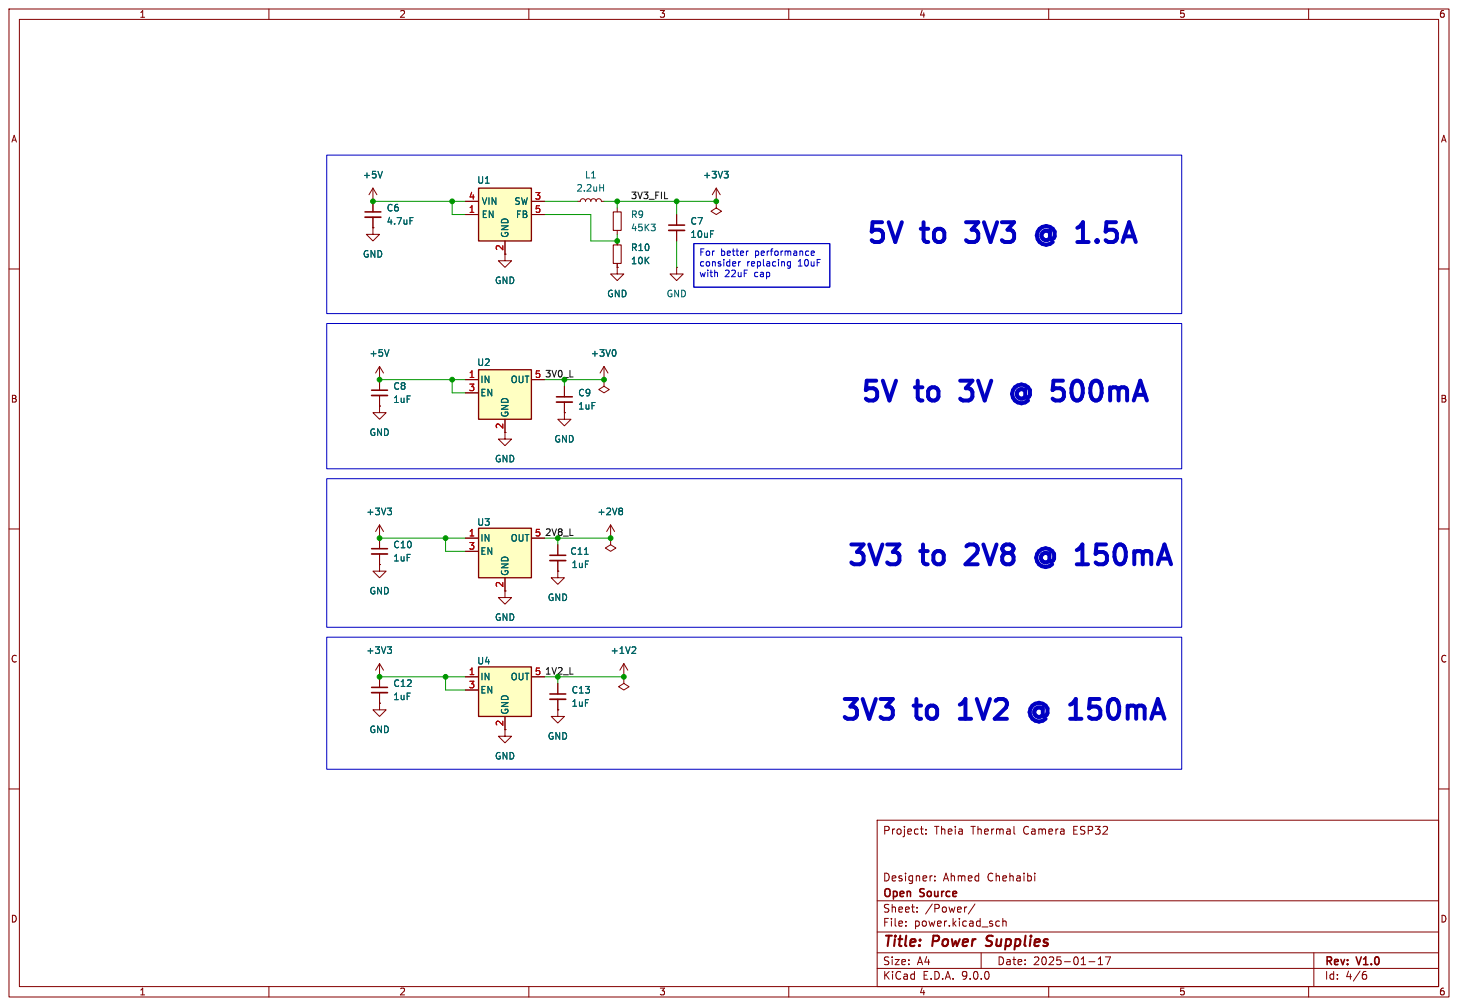
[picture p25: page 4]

Id: 4/6 Title: Power Supplies

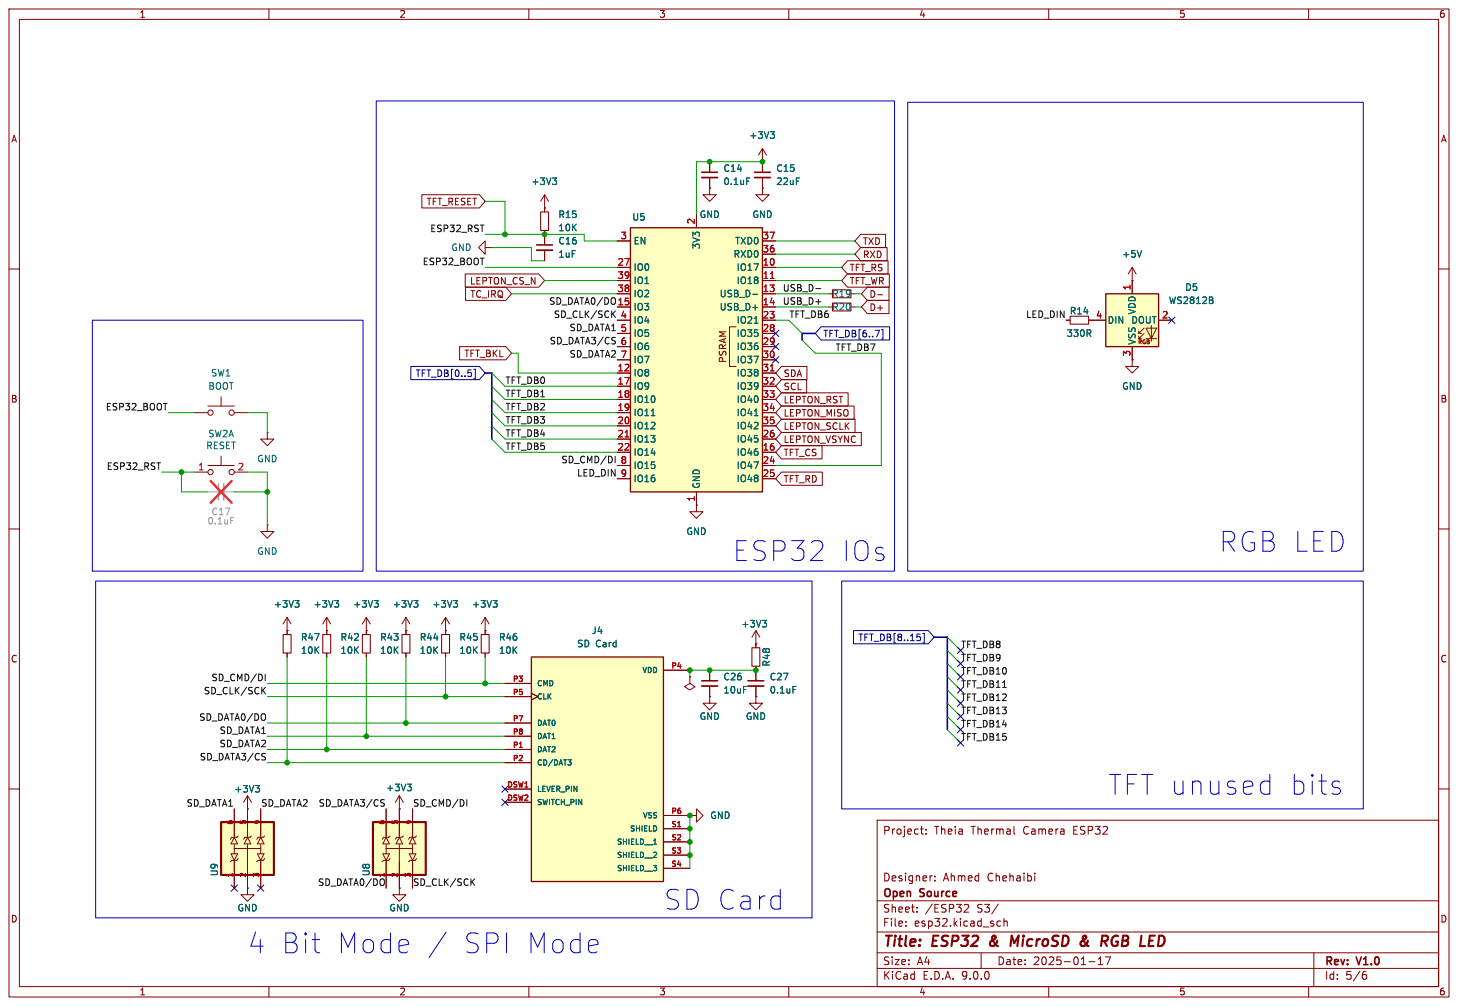
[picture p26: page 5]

4 Bit Mode / SPI Mode

Id: 5/6 Title: ESP32 & MicroSD & RGB LED

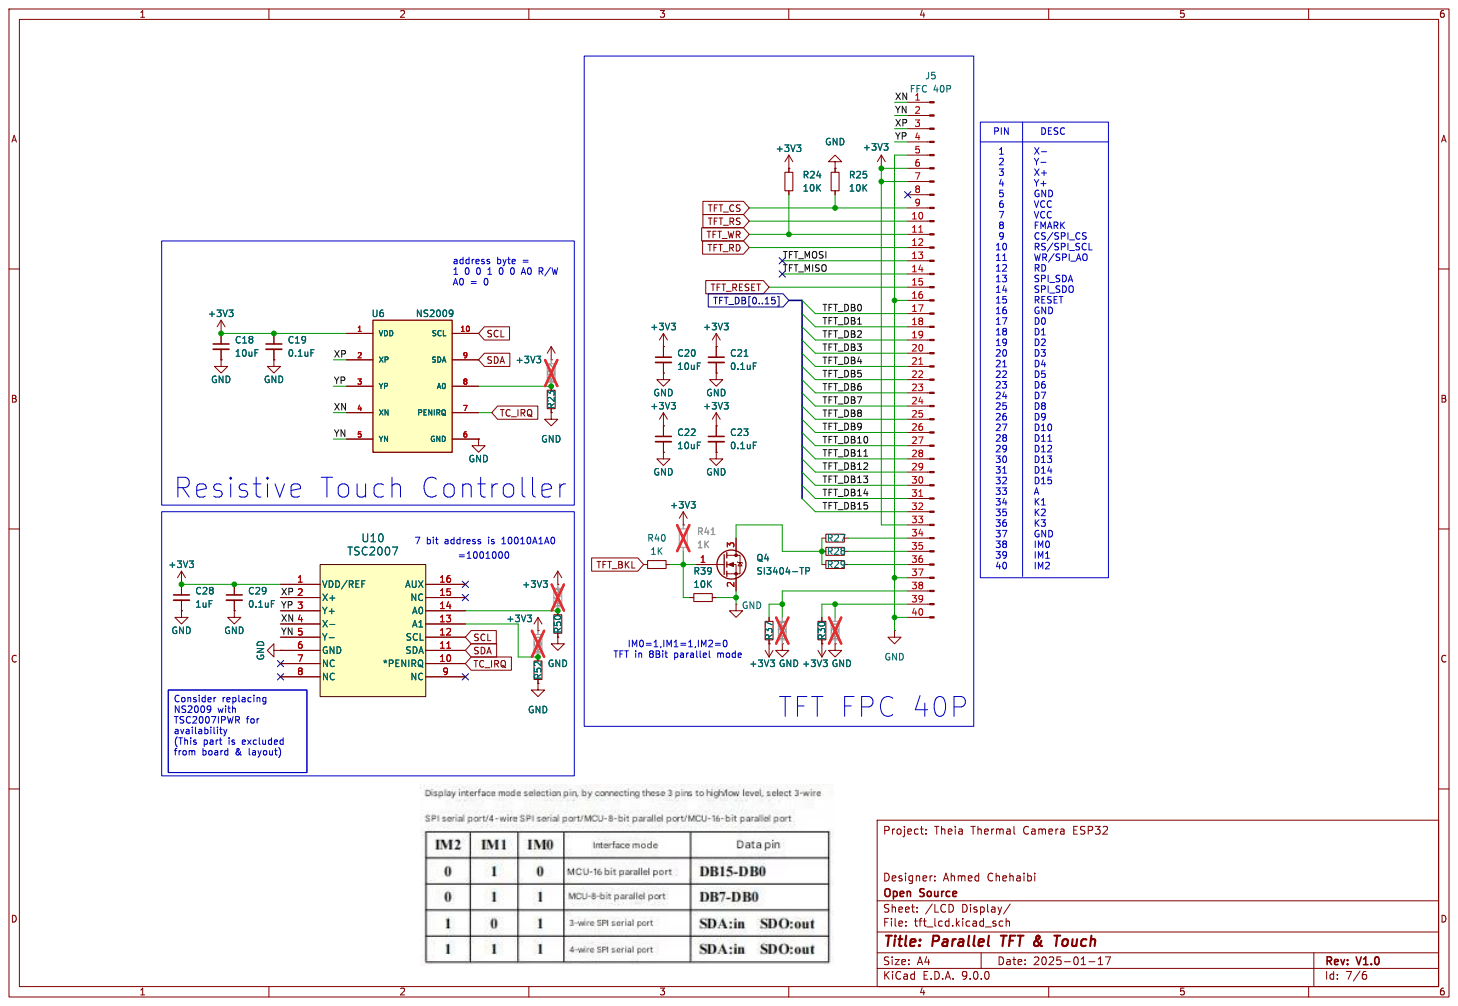
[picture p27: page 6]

VCC
FMARK CS/SPI_CS RS/SPI_SCL WR/SPI_AO

IM2 7 bit address is 10010A1A0 Resistive Touch Controller
TFT_DB13 TFT_DB14 Consider replacing NS2009 with TSC2007IPWR for availability

(This part is excluded

Id: 7/6 Title: Parallel TFT & Touch

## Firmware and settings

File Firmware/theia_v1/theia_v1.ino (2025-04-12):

#include <lvgl.h>
#include <ESP32Time.h>  // RTC for runtime
#include <esp_heap_caps.h>
#include "Globals.h"
#include "Storage.h"
#include "Display.h"
#include "Lepton.h"
#include "StatusLed.h"
#include "Connection.h"
#include "ui.h"
#include "vars.h"

//runtime rtc;
ESP32Time rtc(0);  // offset in seconds GMT+1
// Storage
Storage storage(SD_MMC_CLK, SD_MMC_CMD, SD_MMC_D0, SD_MMC_D1, SD_MMC_D2, SD_MMC_D3);
// Lepton Camera
Lepton lep(LEPTON_VoSPI_SCK, LEPTON_VoSPI_CS, LEPTON_VoSPI_MISO, LEPTON_RST_PIN, LEPTON_VSYNC_PIN);
// Status Led
StatusLed statusled(0);  // default status (No Error)

// Lepton camera
bool lep_rotate_180 = true;
uint8_t lep_version;
// TFT
uint8_t tft_brightness;
// SD Card
uint8_t sdCardState = 0;
const char *img_path = "/Lepton/IMG_";

// GUI
//lvgl buffers
static lv_disp_draw_buf_t lv_draw_buf;
static lv_color_t lv_line_buf[TFT_SCREEN_HEIGHT * 10];

// Tasks
TaskHandle_t gui_task;
TaskHandle_t lep_task;

//
uint32_t startTime_us;
uint32_t endTime_us;


// GUI Helpers
/* Display flushing */
void disp_flush_cb(lv_disp_drv_t *disp, const lv_area_t *area, lv_color_t *color_p) {
  uint32_t w = (area->x2 - area->x1 + 1);
  uint32_t h = (area->y2 - area->y1 + 1);

  tft.startWrite();
  tft.setAddrWindow(area->x1, area->y1, w, h);
  tft.writePixels((lgfx::rgb565_t *)&color_p->full, w * h);
  tft.endWrite();

  lv_disp_flush_ready(disp);
}

/* LVGL Log Callback */
void print_log_cb(const char *text) {
  Serial0.println(text);
  Serial0.flush();
}

/* LVGL Read touch Callback */
void touchpad_read_cb(lv_indev_drv_t *indev_driver, lv_indev_data_t *data) {
  uint16_t touchX, touchY;
  bool touched = tft.getTouch(&touchX, &touchY);
  if (!touched) {
    data->state = LV_INDEV_STATE_REL;
  } else {
    data->state = LV_INDEV_STATE_PR;
    /*Set the coordinates*/
    data->point.x = touchX;
    data->point.y = touchY;
  }
}

/* LVGL RTC 1s Timer Callback */
static void lv_rtc_timer_1s_cb(lv_timer_t *timer) {
  LV_UNUSED(timer);
  set_var_curr_runtime(rtc.getTime("%H:%M:%S").c_str());
}

/* LVGL Sys 3s Timer Callback */
static void lv_sys_timer_3s_cb(lv_timer_t *timer) {
  LV_UNUSED(timer);
  // Check SD card only if in main screen and not saving a photo
  if ((get_var_act_scr_id() == SCREEN_ID_MAIN_SCREEN) && !get_var_lep_snap_to_sd()) {
    if (storage.sdCardInserted()) {
      // SD Card still inserted
      sdCardState = storage.sdCardCheckSpace();
    } else {
      // SD Card removed
      sdCardState = 0;
    }
    set_var_sd_card_state(sdCardState);
  }
}

/* LVGL Init */
void lvgl_init() {
  lv_init();
  lv_disp_draw_buf_init(&lv_draw_buf, lv_line_buf, NULL, TFT_SCREEN_HEIGHT * 10);
  /* Initialize the display driver */
  static lv_disp_drv_t disp_drv;
  lv_disp_drv_init(&disp_drv);
  disp_drv.hor_res = TFT_SCREEN_HEIGHT;
  disp_drv.ver_res = TFT_SCREEN_WIDTH;
  disp_drv.sw_rotate = 1;
  disp_drv.rotated = LV_DISP_ROT_NONE;
  disp_drv.flush_cb = disp_flush_cb;
  disp_drv.draw_buf = &lv_draw_buf;
  lv_disp_drv_register(&disp_drv);
  /* Initialize the (dummy) input device driver */
  static lv_indev_drv_t indev_drv;
  lv_indev_drv_init(&indev_drv);
  indev_drv.type = LV_INDEV_TYPE_POINTER;
  indev_drv.read_cb = touchpad_read_cb;
  lv_indev_drv_register(&indev_drv);
  /* Initialize log callback */
  lv_log_register_print_cb(print_log_cb);
}

void sysTimerInit() {
  /* Initialize first 1s timer */
  lv_timer_t *rtc_timer_1s = lv_timer_create(lv_rtc_timer_1s_cb, 1000, NULL);
  lv_timer_ready(rtc_timer_1s);
  /* Initialize second 3s timer */
  lv_timer_t *sys_timer_3s = lv_timer_create(lv_sys_timer_3s_cb, 3000, NULL);
  lv_timer_ready(sys_timer_3s);
}

void setup() {
  // Initialize serial port
#if defined(USE_DEBUG_SERIAL)
  Serial0.begin(115200);
#endif
  // Init tft
  tft_init();
  // Display Splash Screen
  displayBootScreen();
  // USB CDC
  displayBootLogText("Starting USB CDC...");
  Serial.begin(921600);
  Serial.setTxBufferSize(1024);
  Serial.flush();
  delay(200);
  // LED
  displayBootLogText("Starting StatusLED...");
  statusled.init();
  statusled.setStatus(0);
  delay(200);
  displayBootLogText("Starting Storage...");
  // Init SD card & EEPROM
  sdCardState = storage.init();
  delay(200);
  displayBootLogText("Checking SD Card...");
  set_var_sd_card_state(sdCardState);
  if (sdCardState != 0) {
    // Check if lepton dir exists otherwise create it
    storage.sdCardCheckLeptonDir();
    // Check if .theia file exists otherwise create it
    storage.sdCardCheckTheiaFile();
  }
  delay(200);
  // get settings from persistant storage 
  displayBootLogText("Loading Settings...");
  storage.psLoadInitValues();
  delay(200);
  //LVGL
  lvgl_init();
  displayBootLogText("LVGL Init Done...");
  delay(200);

#if defined(USE_DEBUG_SERIAL)
  // SD Card tests
  if (sdCardState != 0) {
    Serial0.println("======= Testing SD Card ========");
    Serial0.printf("Total space: %lluMB\n", storage.sdCardTotalBytes() / (1024 * 1024));
    Serial0.printf("Used space: %lluMB\n", storage.sdCardUsedBytes() / (1024 * 1024));
    Serial0.println("====== End Testing SD Card =======");
  }
#endif

  displayBootLogText("Waiting for camera startup...");
  delay(1000); // wait for lepton to fully boot
  // Check if lepton is on
  while (!lep.isOn()) {}

  displayBootLogText("Camera boot complete...");
  delay(200);
  lep_version = lep.getPartNumber();

#if defined(USE_DEBUG_SERIAL)
  if (lep_version == LEP_3_5_SHUTTER) {
    Serial0.println("Lepton Version: 3.5 Shutter");
  } else {
    Serial0.println("Lepton Version: UNSUPPORTED");
  }
  Serial0.printf("Lepton Uptime: %d\n", lep.getUpTime());
  Serial0.printf("Lepton case temp: %2.2f°C\n", (lep.getAuxTemp() / 100) - 273.15);
  Serial0.printf("Lepton sensor temp: %2.2f°C\n", (lep.getFpaTemp() / 100) - 273.15);
  Serial0.flush();
#endif

  displayBootLogText("Starting System Tasks & Timers...");
  // Start lepton task
  xTaskCreatePinnedToCore(lepTask, "lep_task", 4096, NULL, 1, &lep_task, 0);
  // Start Gui Task
  xTaskCreatePinnedToCore(guiTask, "gui_task", 4096, NULL, 1, &gui_task, 1);
  sysTimerInit();
  // Turn the LED OFF
  statusled.setStatus(11);
  displayClear();
}

void lepTask(void *pvParameters) {
  // Theory
  // NOTE:  Valid Segment Timing (no loss of synchronization) = 1/106 sec =~ 9434 µs =~ 9.434 ms
  //        => Valid Frame Timing = 4*1/106 =~ 37.736 ms
  // However the rate of unique and valid frames is just below 9 Hz => Valid Frame Timing =~ 112 ms
  // Practice
  // NOTE:  Capture time (No Sync Loss) =~ 60ms
  //        Capture time (With Sync Loss) =~ 60ms - When Sync is lost + numberSyncLoss * SyncTime (n*300ms)
  //                                      => between 300 and 400 ms
  // NOTE:  Display time =~ 164ms

  // Init Hardware
  // Setup the VoSPI bus
  lep.init();
  vTaskDelay(pdMS_TO_TICKS(1000));  // wait 1s
  while (1) {
    // Only capture the image when in main screen (save some processing power?)
    if (get_var_act_scr_id() == SCREEN_ID_MAIN_SCREEN) {
      lep.captureImage(lep_rotate_180);
      // TODO: only update the buffer when valid image is captured
      lep.updateRamBuffer();
      // If take a snap is triggered
      if (get_var_lep_snap_to_sd()) {
        bool success = false;
        bool isBmp = get_var_image_format();
        char *img_name;
        char index_buffer[5];
        // get last file index from storage
        uint16_t index = storage.psGetImageIndex() + 1;
        ultoa(index, index_buffer, 10);
        img_name = (char *)heap_caps_malloc(SAVED_FILE_PATH_MAX_CHARS, MALLOC_CAP_SPIRAM);
        strcpy(img_name, img_path);
        strcat(img_name, index_buffer);
        if (isBmp) {
          strcat(img_name, ".bmp");
          success = lep.saveBMPImage(img_name);

        } else {
          strcat(img_name, ".timg");
          success = lep.saveRAWImage(img_name);
        }
        heap_caps_free(img_name);
        create_save_notification(success, isBmp);
        if (success) {
          // Commit the new index on success
          storage.psCommitImageIndex(index);
        }
        set_var_lep_snap_to_sd(false);
      }
      // If transfer raw data is triggered
      if (get_var_lep_transfer_raw()){
        lep.transferImage();
        set_var_lep_transfer_raw(false);
      }
      // If transfer lepton status is triggered
      if (get_var_lep_transfer_status()){
        lep.transferStatus();
        set_var_lep_transfer_status(false);
      }
    }
    // NOTE: Read Globals.h for wait period...
    vTaskDelay(pdMS_TO_TICKS(LEP_IMAGE_CAPTURE_PERIOD_MS));
  }
  vTaskDelete(NULL);
}

void guiTask(void *pvParameters) {
  // GUI Init
  ui_init();
  while (1) {
    lv_timer_handler(); /* let the GUI do its work */
    ui_tick();
  }
  vTaskDelete(NULL);
}

void loop() {
  // system:
  // check and update the GUI icons, messages ... etc
  /* Settings Screen handeling */
  if (get_var_lep_reboot()) {
    statusled.setStatus(1);
    lep.reboot();  // reboot the lepton
    set_var_lep_reboot(false);
    statusled.setStatus(11);
  }
  // if reset lepton is triggered
  if (get_var_lep_rst()) {
    statusled.setStatus(2);
    // Hard reset the camera
    lep.reset();
    set_var_lep_rst(false);
    statusled.setStatus(11);
  }
  // if set gain is triggered
  if (get_var_set_gain_trig()) {
    uint8_t gain = get_var_lepton_gain_mode();
    lep.setGainMode(gain);
    // update persistant storage
    storage.psCommitByte(PS_RAM_LEP_GAIN_MODE_ADDR, gain);
    set_var_set_gain_trig(false);
  }
  // if get debug triggered
  if (get_var_dbg_info_trig()) {
    int i = 0;
    i = append_cam_revision(i);
    i = append_fw_version(i);
    i = append_sdk_version(i);
    i = append_lepton_info(i, lep_version,
                           ((lep.getFpaTemp() / 100) - 273.15),
                           ((lep.getAuxTemp() / 100) - 273.15));
    i = append_storage_info(i, get_var_sd_card_state() != 0,
                            storage.sdCardTotalBytes() / (1024 * 1024),
                            storage.sdCardUsedBytes() / (1024 * 1024),
                            storage.sdCardGetNbrOfFiles());
    i = append_mem_info(i);
    i = append_copyright(i);
    set_var_dbg_info_trig(false);
    update_dbg_msg();
  }
  // run FFC is triggered
  if (get_var_run_ffc_trig()) {
    set_var_run_ffc_trig(false);
    lep.runFFC();
  }
  // If brightness changed
  if (tft_brightness != get_var_brightness_value()) {
    tft_brightness = get_var_brightness_value();
    setDisplayBrightness(tft_brightness * 255 / 100);
  }
  /* Update storage triggers handeling */
  if (get_var_update_palette_trig()) {
    set_var_update_palette_trig(false);
    uint8_t pal = get_var_palette_num();
    storage.psCommitByte(PS_RAM_PALETTE_NUM_ADDR, pal);
  }
  if (get_var_update_temp_unit_trig()) {
    set_var_update_temp_unit_trig(false);
    uint8_t unit = get_var_cur_temp_format();
    storage.psCommitByte(PS_RAM_LEP_TEMP_UNIT_ADDR, unit);
  }
  if (get_var_update_img_format_trig()) {
    set_var_update_img_format_trig(false);
    uint8_t format = (uint8_t) get_var_image_format();
    storage.psCommitByte(PS_RAM_LEP_IMG_FORMAT_ADDR, format);
  }
  /* Browse Screen handeling */
  // if browse start triggered
  if (get_var_browse_start_trig()) {
    set_var_browse_start_trig(false);
    storage.startBrowseSession();
  }
  /* Serial comm handeling */
  if (commandReceived()) {
    handleCommand();
  }

  vTaskDelay(pdMS_TO_TICKS(50));  // wait 50 ms
}

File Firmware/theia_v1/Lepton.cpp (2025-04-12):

#include <Arduino.h>
#include <Wire.h>
#include <SPI.h>
#include <FS.h>
#include "Lepton.h"
#include "Globals.h"
#include "vars.h"
#include "screens.h"
#include "Storage.h"
#include "CRC8.h"
#include "CRC.h"
#include "esp_log.h"

static const char* TAG = "Lepton";

// CRC For Serial transfer
CRC8 lepCRC;
// VoSPI Frequency
static const int vospiClkFreq = 20000000;  // 20 MHz, min is 2.2, max 20 for the Lepton 3.5 module.
// SPI bus which will implement the Lepton VoSPI
SPIClass* hspi = NULL;
// VoSPI data buffers
uint16_t lepton_frame_packet[LEP_VOSPI_FRAME_SIZE / 2];
uint16_t lepton_frame_segment[60][LEP_VOSPI_FRAME_SIZE / 2];  // 60 packets per segment
// Image buffer
static uint16_t lepton_image_buf[LEP_IMAGE_X][LEP_IMAGE_Y];


double lep_max_temp = 0;
double lep_min_temp = 0;
double lep_min, lep_max;
double lep_pointer_temp = 0;
char lep_min_temp_chr[10];
char lep_max_temp_chr[10];
char lep_pointer_temp_chr[10];
bool agc_enabled = false;
lepDiagnostics_t lepDiagnostics;

Lepton::Lepton(int vospiClk, int vospiCS, int vospiMiso, int rstPin, int vsyncPin) {
  _vospiClk = vospiClk;
  _vospiCS = vospiCS;
  _vospiMiso = vospiMiso;
  _rstPin = rstPin;
  _vsyncPin = vsyncPin;  // Not used for now
}

/***********/
/*  VoSPI  */
/***********/
/* Initialize Lepton VoSPI with the selected pins */
void Lepton::init() {
  //ESP_LOGI(TAG, "Starting VoSPI over HSPI...");
  hspi = new SPIClass(HSPI);
  hspi->begin(_vospiClk, _vospiMiso, -1, _vospiCS);
  hspi->setDataMode(SPI_MODE3);
  pinMode(_vospiCS, OUTPUT);
  digitalWrite(_vospiCS, HIGH);
  pinMode(_rstPin, OUTPUT);
  digitalWrite(_rstPin, LOW);
  pinMode(_vsyncPin, INPUT);
  // Init lepton image buffer
  gui_lep_canvas_buffer = (uint16_t*)heap_caps_malloc(GUI_LEPTON_IMAGE_WIDTH * GUI_LEPTON_IMAGE_HEIGHT * 2, MALLOC_CAP_SPIRAM);
  if (gui_lep_canvas_buffer == NULL) {
    ESP_LOGE(TAG, "malloc GUI canvas buffer failed");
  }
  lepDiagnostics.syncErrorCounter = 0;
  lepDiagnostics.validFrameCounter = 0;
  // Perform an FFC
  runFFC();
}

/* Reset the Lepton Camera */
void Lepton::reset() {
  //ESP_LOGI(TAG, "Resetting the Lepton Camera...");
  show_settings_screen_msgbox("Resetting Camera...");
  digitalWrite(_rstPin, HIGH);
  delay(5);
  digitalWrite(_rstPin, LOW);
  // 950 ms required after deasserting RST pin
  // 2.1.1.1 Start-up command sequence (flir software IDD) 110-0144-04 Rev 303
  delay(1000);
  hide_settings_screen_msgbox();
}

bool Lepton::isOn() {
  Wire.beginTransmission(LEP_CCI_DEVICE_ADDRESS);
  uint8_t error = Wire.endTransmission();
  return (error == 0);
}

/* Syncing VoSPI */
// according to 4.2.3.3.1 Establishing/Re-Establishing Sync (lepton datasheet)
void Lepton::softSync() {
  //ESP_LOGI(TAG, "Establishing Sync");
  int i;
  int data = 0x0f00;

  digitalWrite(_vospiCS, HIGH);
  delay(300);  // Waits for the required time indicated by datasheet, ensures a timeout of VoSPI I/F

  while ((data & (0x0f00)) == 0x0f00) {  // I changed this because I don't think it was right

    // begin checking the first returned data packet, should be a discard packet

    // Start of VoSPI transfer for first packet, reading for discard packet
    digitalWrite(_vospiCS, LOW);
    hspi->beginTransaction(SPISettings(vospiClkFreq, MSBFIRST, SPI_MODE3));  // these arent included in others' code
    data = hspi->transfer(0x00) << 8;
    data |= hspi->transfer(0x00);
    // hspi->endTransaction();
    digitalWrite(_vospiCS, HIGH);

    // Process and discard the remaining data in the packet
    for (i = 0; i < ((LEP_VOSPI_FRAME_SIZE - 2) / 2); i++) {
      digitalWrite(_vospiCS, LOW);
      hspi->transfer(0x00);  // unused garbage data
      hspi->transfer(0x00);  // unused garbage data
      digitalWrite(_vospiCS, HIGH);
    }

    hspi->endTransaction();
  }
}

/* capturing a VoSPI frame (4 segments) */
void Lepton::captureImage(bool rotate180) {

  hspi->setDataMode(SPI_MODE3);
  hspi->setFrequency(vospiClkFreq);

  bool collectedSegments[4];
  collectedSegments[0] = false;
  collectedSegments[1] = false;
  collectedSegments[2] = false;
  collectedSegments[3] = false;
  uint8_t lastFoundSegment = 0;
  uint8_t segmentsRead = 0;

  while (!collectedSegments[0] | !collectedSegments[1] | !collectedSegments[2] | !collectedSegments[3]) {

    // Get 60 valid packets per segment
    for (int packetNumber = 0; packetNumber < 60; packetNumber++) {
      do {
        digitalWrite(_vospiCS, LOW);
        hspi->beginTransaction(SPISettings(vospiClkFreq, MSBFIRST, SPI_MODE3));
        byte dummyBuffer[164];
        hspi->transfer(dummyBuffer, sizeof(dummyBuffer));

        for (int i = 0; i < 164l; i += 2) {
          lepton_frame_packet[i / 2] = dummyBuffer[i] << 8 | dummyBuffer[i + 1];
        }

        hspi->endTransaction();
        digitalWrite(_vospiCS, HIGH);
      } while (((lepton_frame_packet[0] & 0x0f00) >> 8 == 0x0f));  // wait until a non-discard packet has been found

      // Load the packet into the segment
      for (int i = 0; i < LEP_VOSPI_FRAME_SIZE / 2; i++) {
        lepton_frame_segment[packetNumber][i] = lepton_frame_packet[i];
      }
    }

    // Load the collected segment into the image after it's all been captured
    int segmentNumber = (lepton_frame_segment[20][0] >> 12) & 0b0111;  // This should give the segment number which is held at packet 20. The transmitted packets start at number 0.

    if (segmentNumber != 0) {  // if the segment is number 0, ignore the segment
      // Makes sure that we get the segments in the right order
      if (segmentNumber == 2) {
        if (!collectedSegments[0]) {  // We haven't found the first segment
          lastFoundSegment = 0;
          segmentsRead = 0;
          lepDiagnostics.syncErrorCounter++;
          softSync();
          break;
        }
      } else if (segmentNumber == 3) {
        if (!collectedSegments[0] && !collectedSegments[1]) {
          lastFoundSegment = 0;
          segmentsRead = 0;
          lepDiagnostics.syncErrorCounter++;
          softSync();
          break;
        }
      } else if (segmentNumber == 4) {
        if (!collectedSegments[0] && !collectedSegments[1] && !collectedSegments[2]) {
          lastFoundSegment = 0;
          segmentsRead = 0;
          lepDiagnostics.syncErrorCounter++;
          softSync();
          break;
        }
      }


      segmentsRead++;
      if (segmentsRead > 4) {  // This means that we're probably out of sync for some reason
        collectedSegments[0] = false;
        collectedSegments[1] = false;
        collectedSegments[2] = false;
        collectedSegments[3] = false;
        lastFoundSegment = 0;
        segmentsRead = 0;
        lepDiagnostics.syncErrorCounter++;
        softSync();
        break;
      }

      if (segmentNumber > 4) {
        lepDiagnostics.syncErrorCounter++;
        softSync();
        break;
      }
      collectedSegments[segmentNumber - 1] = true;
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

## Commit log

2025-04-12 update files & add TheiaTool
    updates to firmware:
    * Fixing typos
    * Fixing some command response length
    Adding Theia Tool v1.0.0b
    [Connection.cpp, Lepton.cpp]
2025-05-14 added PCB order details
2025-05-14 added pcb order info

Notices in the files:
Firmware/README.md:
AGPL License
